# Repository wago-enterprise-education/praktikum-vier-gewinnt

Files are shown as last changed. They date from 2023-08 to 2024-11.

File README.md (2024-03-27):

<meta http-equiv="refresh" content="0; url=https://wago-enterprise-education.github.io/praktikum-vier-gewinnt/docs/index.html">

# Praktikantenprojekt "Vier-Gewinnt"

## Kurzer Überblick

Bei diesem Projekt handelt es sich um ein Projekt für einen Praktikanten welches in der vollständigen Durchführung in etwa 1-3 Tage dauert. Basis des Projekts ist der ESP32. Ziel dabei ist, dass der Praktikant die Grundlagen der Microcontrollerprogrammierung und der Elektronik sowie des Lötens erlernt. Eine kurze Beschreibung des PCBs und der Bedienung kann [hier](docs/Platinenbeschreibung-VierGewinnt.pdf) gefunden werden. Bei Problemen oder Rückfragen kann sich an [uns](#ansprechpartner) gewendet werden.

## Ablauf des Praktikums

### Praktikumsdauer: 1 Tag
1. Vollständiges Löten und Zusammenbauen des Gerätes mithilfe der [Lötanleitung](docs/LoetAnleitung.pdf)
2. Auseinandersetzung mit dem [Aufbau und der Funktionsweise](docs/Platinenbeschreibung-VierGewinnt.pdf) des Spiels

### Praktikumsdauer: 2 - 3 Tage
1. [Aufbau und Programmierung einfacher Schaltungen auf dem Steckbrett](docs/Aufgabenstellung.pdf)
2. Vollständiges Löten und Zusammenbauen des Gerätes mithilfe der [Lötanleitung](docs/LoetAnleitung.pdf)
3. Auseinandersetzung mit dem [Aufbau und der Funktionsweise](docs/Platinenbeschreibung-VierGewinnt.pdf) des Spiels

## Informationen zur Programmierung des Moduls

Zur Programmierung können entweder die "Arduino-IDE" oder "Visual Studio Code" benutzt werden. Programmiert wird auf dem Breakout-Board "DOIT ESP32 DEVKIT V1".

## Hinweise

Während der Bestellung bitte darauf achten, dass bei der Option "Remove Order Number", "Specify a Location" ausgewählt ist.

## Ansprechpartner

<max.steidle@wago.com>

<lucas.krietenstein@wago.com>

<andreas.epp@wago.com>

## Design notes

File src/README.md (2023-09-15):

# Quellcode des Spiels: Vier-Gewinnt
Hier kann der gesamte Quellcode des Spiels gefunden werden. Je nach Ordner, entweder für die Arduino IDE oder für Visual Studio Code.

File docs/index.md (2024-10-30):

---
layout: page
title: 4-Gewinnt
lang: de
lang-ref: index
---

## Kurzer Überblick

Hallo und willkommen bei Ihrem Praktikum bei WAGO. In diesem Modul geht es darum, Vier-Gewinnt aufzubauen, zu löten und gegebenenfalls zu programmieren. Eine kurze Beschreibung des Aufbaus und der Bedienung des Spiels kann [hier](Platinenbeschreibung-VierGewinnt.pdf) gefunden werden. In dem WAGO-Karton den Sie bekommen haben befinden sich alle notwendigen Bauteile, um Vier-Gewinnt aufbauen zu können. Am besten prüfen Sie einmal ob alle Bauteile vorhanden sind. Anhand [dieser Bauteilliste](Bauteilliste.pdf) können Sie sicherstellen, dass der Bausatz vollständig und korrekt ist. Bei Problemen oder Rückfragen können Sie sich gerne an [Herrn Rehburg oder Herr Lauxtermann wenden.](#ansprechpartner)

## Aufbauanleitung

Wenn Sie sichergestellt haben dass der Bauteilsatz vollständig ist, können Sie mit dem Aufbau starten. Um das Spiel aufbauen zu können, werden alle Bauteile in dem WAGO-Karton benötigt. Die Platine dient dabei als Bauteilträger, dort werden also alle Bauteile (Mit Ausnahme des ESP32 und der 9 V Batterie) angelötet. Bevor Sie mit dem Löten anfangen können muss zunächst einmal der Arbeitsplatz eingerichtet werden. Wie er beispielhaft aussehen kann sehen Sie [hier](Arbeitsplatzausstattung.pdf). Wie Sie beim Löten am besten vorgehen wird [hier](LoetAnleitung.pdf) erklärt. Wenn Sie sich an der Anleitung hangeln sollte es beim Aufbau des Spiels keine Probleme geben.

## Informationen zur Programmierung des Moduls

Wenn Sie das Spiel aufgebaut haben können Sie anfangen zu programmieren. Um die Programmierumgebung "Arduino" einmalig einzurichten können Sie sich an [diese Anleitung](Programmierung.pdf) halten. Zur Programmierung können wahlweise entweder die "Arduino-IDE" oder "Visual Studio Code" benutzt werden. Programmiert wird auf dem Breakout-Board "DOIT ESP32 DEVKIT V1". Der fertige Code mit den aktuellen lauffähigen Programmen für Visual Studio Code und Arduino und den Vorlagen der Aufgaben können unter [diesem Link](Bundle.7z) als Zip-Datei heruntergeladen werden. Spielen Sie am am besten das fertige Programm einmal auf den Mikrocontroller um zu prüfen, ob Sie alles richtig verlötet haben. Die Bedienung des Geräts kann [hier](Platinenbeschreibung-VierGewinnt.pdf) nachgelesen werden.

## Aufgaben

Sie haben das Programm auf den ESP32 geladen und alles hat funktioniert? Sehr gut! Dann können Sie mit den nächsten Aufgabenstellungen starten. Im Falle, dass das Spiel noch nicht funktioniert, müssen Sie ihre Platine nochmal überprüfen.

### Aufgabensatz 1

Um das technische Prinzip der LED-Matrix zu verstehen können Sie [diese Aufgaben](Aufgabenstellung.pdf) bearbeiten.

### Aufgabensatz 2

In [diesem Aufgabensatz](ErweiterteAufgaben.pdf) können Sie selbst Hand an den Code legen, sich in den Programmcode hinein arbeiten und einige Zeilen Code eigenständig schreiben. Das dazugehörige Programm ist in vorangegangener Zip-Datei zu finden. Das Programm der Aufgabenstellung muss von Ihnen ergänzt werden.

## Ansprechpartner

<maik.rehburg@wago.com>

<tobias.lauxtermann@wago.com>

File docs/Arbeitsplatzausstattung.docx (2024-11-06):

## Arbeitsplatzausstattung Löten:

Bevor ihr mit der Lötarbeit eures Aufbaus beginnt, solltet ihr den Arbeitsplatz mit den untenstehenden Materialien und Werkzeugen bestücken.

Die Bauteile, Werkzeuge und Materialien solltet ihr in den Blechschränken bzw. Lagertürmen im Elektroniklabor finden, sofern keine anderen Angaben gemacht worden sind. Der fertig bestückte Arbeitsplatz (ohne Materialien) für den Projektaufbau sollte in etwa so aussehen:

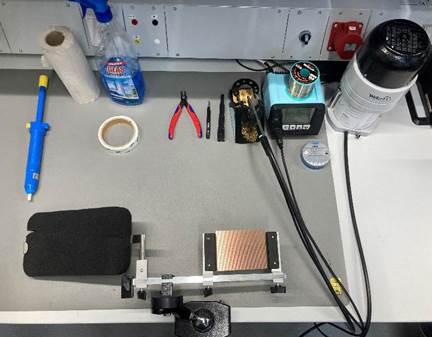
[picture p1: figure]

Lötkolbenset

Absaugung

Lötzinn

Biegelehre

Entlötpumpe

Elektronik-Seitenschneider

Pinzette

Lötfett

Platinenhalterung

Doppelseitiges Klebeband

Glasreiniger

Papier

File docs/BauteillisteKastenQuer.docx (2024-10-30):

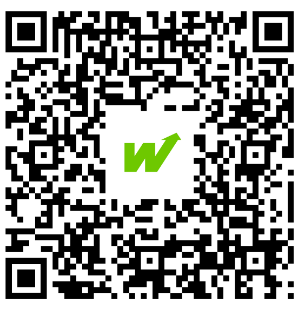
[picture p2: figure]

# Stückliste

Bauteil | Menge | Bauteil | Menge
PCB (Vier-Gewinnt) | 1 | Duo-LED | 30
ESP32 | 1 | Taster | 4
9V Batterie | 1 | Schiebeschalter (angewinkelt) | 1
10 kΩ Widerstände | 4 | Spannungsregler (L7805ACV) | 1
Buchsenleiste (15 Pin) | 2 | Keramikkondensator (330 nF) | 1
Batterieclip | 1 | Keramikkondensator (100 nF) | 1

# Stückliste

Bauteil | Menge | Bauteil | Menge
PCB (Vier-Gewinnt) | 1 | Duo-LED | 30
ESP32 | 1 | Taster | 4
9V Batterie | 1 | Schiebeschalter (angewinkelt) | 1
10 kΩ Widerstände | 4 | Spannungsregler (L7805ACV) | 1
Buchsenleiste (15 Pin) | 2 | Keramikkondensator (330 nF) | 1
Batterieclip | 1 | Keramikkondensator (100 nF) | 1

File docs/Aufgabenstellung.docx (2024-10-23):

# Praktikantenaufgabe “Vier Gewinnt”

# Benötigte Materialien:

- ESP32
- Steckbrett
- Jumperkabel
- 220 Ω Widerstände
- LEDs beliebiger Farbe

# Aufgabenstellung:

Für die kommenden Aufgaben nutzen Sie ein Steckbrett, auf dem Sie verschiedene Schaltungen aufbauen. Auf einem solchen Steckbrett sind die Verbindungspunkte immer entweder in einer Zeile oder Spalte miteinander verbunden, das ist in der folgenden Grafik durch die orangen Linien dargestellt. Stecken Sie den ESP32 wie in der Abbildung dargestellt auf das Steckbrett.

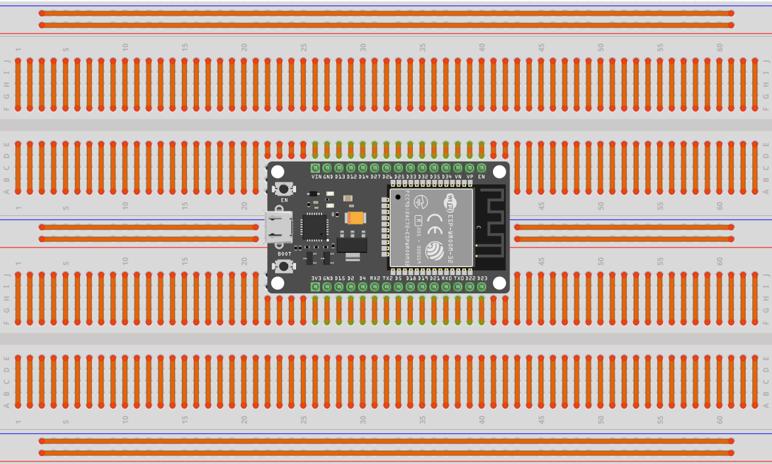
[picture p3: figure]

# Aufgabe 1: Aufbau einer LED

In dieser Aufgabe sollen Sie Leuchtdioden (LEDs) kennenlernen. Wenn durch eine LED-Strom fließt, leuchtet sie. Ist der Strom zu groß, brennt sie durch. Um das zu verhindern, muss immer ein sogenannter Vorwiderstand zwischen der Stromquelle und der LED („vor der LED“) eingebaut werden. Für die folgenden Aufgaben nutzen Sie bitte immer einen 220 Ω Vorwiderstand.

Wenn Sie die LED anschauen, fällt auf, dass sie nicht symmetrisch aufgebaut ist, sondern einer der Anschlussdrähte länger ist. Der lange Anschlussdraht ist der Plus-Pol der LED, der kurze der Minus-Pol (an dieser Seite ist auch das Gehäuse der LED abgeflacht, auch daran können Sie die Seite unterscheiden).

Bauen Sie die Steckbrett-Schaltung der folgenden Abbildung auf. Vom „GND“-Pin des ESP32 gehen Sie mit einer Jumper-Leitung dabei auf die blau markierte Reihe, von dem „3V3“-Pin auf die rot markierte Reihe. Sie können für spätere Schaltungen dann Ground (0V) bzw. 3,3V von diesen Reihen übernehmen.

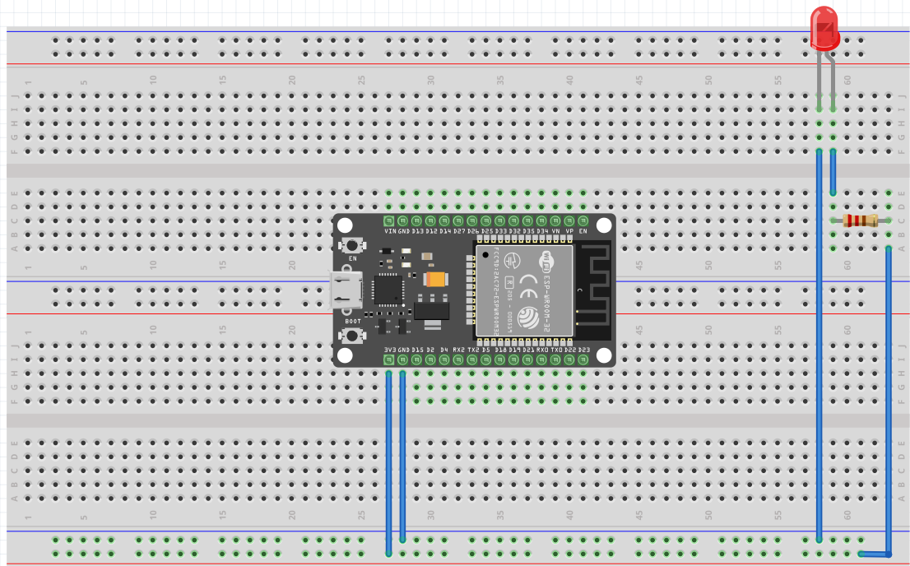
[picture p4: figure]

# Aufgabe 2: LED blinken lassen

Mit dem Aufbau der vorherigen Aufgabe liegt immer Spannung an der LED an und sie leuchtet immer. Wir wollen sie aber selbst ein- und ausschalten können. Dafür nutzen wir einen Ausgangspin der ESP32, den wir programmieren können. Bauen Sie als erstes diese Schaltung auf und öffnen Sie ein neues Projekt in der Arduino IDE:

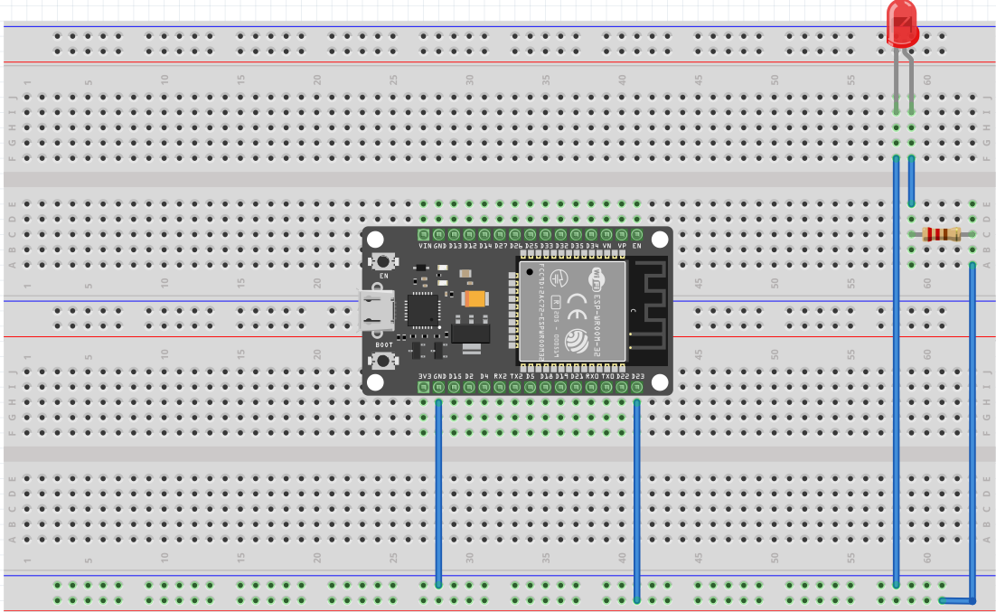
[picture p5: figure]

Der Ausgang, an dem der Widerstand angeschlossen ist, ist mit „D23“ bezeichnet. Das ist der Pin mit der Nummer 23. Damit wir nicht im Programm die Nummer verwenden müssen, um die LED ansteuern zu können, „merken“ wir uns den Pin und definieren dafür eine eigne Bezeichnung. Das macht man durch #define<Platzhalter> <Wert>, dass man über die loop()- und setup()-Funktion schreiben. In diesem Fall also: #define LED 23

Jetzt müssen wir noch konfigurieren, dass dieser Pin als Ausgang genutzt werden soll. Das muss nur einmal beim Starten des ESP32 ausgeführt werden und wird daher in der setup()-Funktion geschrieben. Die Funktion, um einen digitalen Ein- oder Ausgang zu konfigurieren ist pinMode(<Pin>, <INPUT/OUTPUT>). Für alle Stellen im Programm, in denen die Pin-Nummer benötigt wird, können wir jetzt den Platzhalter eintragen, also:

pinMode(LED, OUTPUT);

Damit „weiß“ das Programm, dass dieser Pin, an den die LED über den Vorwiederstand angeschlossen ist, einen Wert High/Low ausgeben soll. Das müssen wir im nächsten Schritt auf diesen Pin schreiben. Das soll immer wieder passieren, muss also in die loop()-Funktion geschrieben werden. Wir wollen einen digitalen Wert schreiben auf den Ausgang, genauso heißt auch die Funktion

digitalWrite(LED, HIGH);

Damit wird die LED eingeschaltet. Um sie wieder auszuschalten, schreibt man LOW statt HIGH. Eine blinkende LED schaltet immer zwischen an und aus – mit einem zeitlichen Versatz dazwischen. Um eine gewisse Zeit zu warten nutz man

delay(<Zeit in Millisekunden>);

Nutzen Sie die Funktionen, die Sie kennengelernt haben und lassen Sie die LED in regelmäßigen Zeitabständen (z.B. 2 Sekunden) blinken

# Aufgabe 3: Masse schalten

So wie man einen Pin des ESP32 als digitalen Ausgang nutzen und programmieren kann, um eine Spannung auszugeben, kann man auch einen Pin dafür verwenden, um Masse zu schalten (also 0V ausgeben). Bauen Sie zuerst die folgende Schaltung auf dem Steckbrett nach:

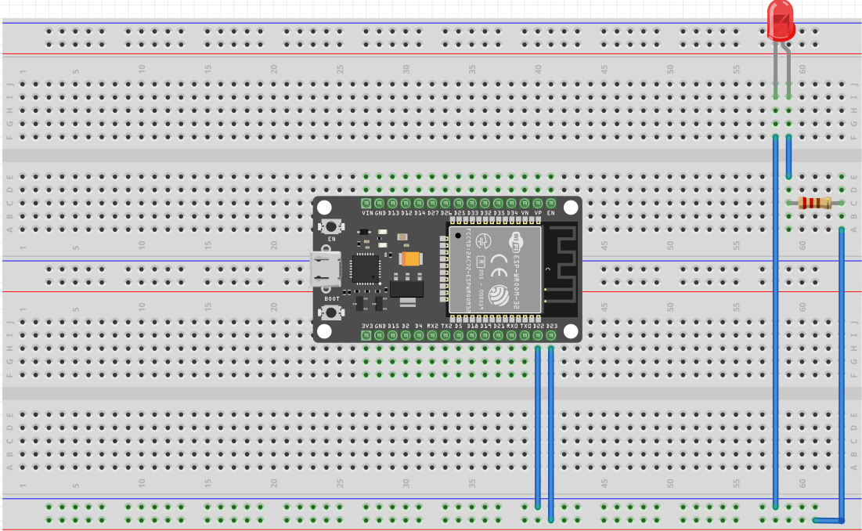
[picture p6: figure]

Die Masse liegt nun auf dem Pin „D22“ diesen können Sie sich wieder in einem Platzhalter abspeichern, um diesen im restlichen Programm zu verwenden. Außerdem muss dieser Pin ebenfalls in der setup()-Funktion als Ausgang konfiguriert werden. Im Anschluss können Sie diesen Pin wieder in der loop()-Funktion programmieren. Um Masse zu schalten, wird dieselbe Funktion, wie zum Ein- und Ausschalten der LED verwendet, da es nichts anderes ist, als eine Spannung von 0V (also LED ausschalten) abzugeben. Versuchen Sie die LED wieder zum Blinken zu bekommen, indem Sie über den Pin 23 konstant eine Spannung von 3,3V anlegen und nur über den Masse-Pin 22 die LED steuern.

# Aufgabe 4: Eigene LED-Matrix

Da unser 4-Gewinnt Spielfeld aus 6 Spalten und 5 Reihen besteht, benötigen Sie 30 LEDs. So viele programmierbare Ausgänge besitz der ESP32 allerdings nicht. Aus diesem Grund müssen Sie sich mit einem „Trick“ behelfen. Jede LED einer Zeile Ihrer eigenen LED-Matrix wird mit demselben Pin verbunden, der eine Spannung von 3,3V abgibt, und jede LED einer Spalte wird mit demselben Pin verbunden, über den Sie dann für die Spalte Masse schalten können. Somit brauchen wir nur 11 Pins (6 Spalten + 5 Zeilen) anstelle von 30. Wie steuert man nun einzelne LEDs auf der Matrix an?

Das System funktioniert wie ein Graph mit einer x- und einer y-Achse. Möchte man eine bestimmte LED ansteuern schaltet man Masse auf der passenden Spalte (die x Koordinate) und die Spannung auf der Passenden Zeile (die y Koordinate). Alle anderen Spalten und Zeilen werden nicht angesteuert und aus diesem Grund leuchtet nur die gewünschte LED.

Bauen Sie den folgenden Schaltplan auf dem Steckbrett nach. Dieser Aufbau demonstriert das Prinzip auf einer kleinen 2x2 Matrix. Dabei ist die Zeile 1 (das linke LED-Paar) mit dem Pin „D13“ verbunden und die Zeile 2 mit dem Pin „D22“. Außerdem ist die erste Spalte (die beiden linken LEDs der LED-Paare) mit dem gemeinsamen Pin „D12“ und die zweite Spalte mit dem Pin „D23“ verbunden.

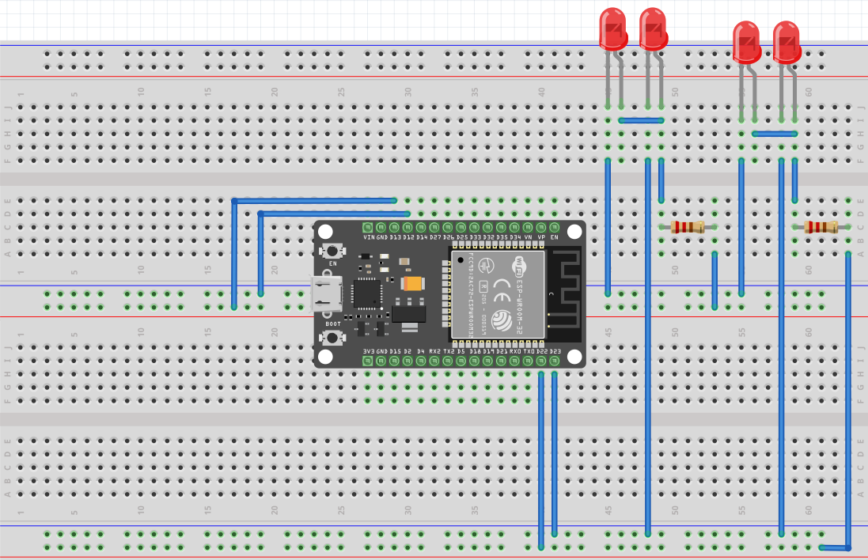
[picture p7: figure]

Versuchen Sie die LED, die in der ersten Spalte und in der ersten Zeile liegt, einzuschalten, ohne das eine andere LED leuchtet.

Beim 4-Gewinnt Spiel leuchtet allerdings nicht immer nur eine LED, sondern viele LEDs gleichzeitig. Was Passiert, wenn Sie versuchen, zwei diagonale LEDs anzusteuern (z.B. Zeile 1, Spalte 1 und Zeile 2, Spalte 2)?

Wie Sie gemerkt haben, leuchten alle 4 LEDs auf, was auch logisch ist, wenn man näher darüber nachdenkt. Aus diesem Grund benötigen Sie einen zweiten „Trick“. Steuern Sie nun die LEDs spaltenweise und zeitversetzt an. Dadurch verhindern wir das LEDs zeitgleich leuchten, die nicht zusammen leuchten sollten. Diesen Vorgang wiederholen wir in einer so hohen Frequenz, dass unser Auge nicht wahrnimmt, dass die LEDs ständig ein- und ausgeschaltet werden. Schreiben Sie ein Programm, dass die eine LED einschaltet und für einen kurzen Moment (z.B. 1 Millisekunde) leuchten lässt. Im Anschluss soll diese LED wieder ausgeschaltet werden und die diagonal gegenüberliegende LED soll für einen kurzen Moment leuchten. Durch die Arbeitsweise der loop()-Funktion wird dieser Vorgang kontinuierlich wiederholt (Tipp: um das Programm zu Pausieren können Sie wieder die Funktion delay() verwenden).

Wenn Sie das Programm richtig geschrieben haben, sollten nun nur die beiden LEDs auf einer Diagonalen zeitgleich leuchten. Dies ist aber, wie Sie nun wissen, nur die halbe Wahrheit. Sie können mit der Verzögerung rumexperimentieren und testen mit welcher Frequenz unser Auge die Täuschung bemerkt.

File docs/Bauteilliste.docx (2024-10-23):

# Bauteilliste

Bauteil | Anzahl | Beschreibung
Platine | 1 | Der Bauteilträger auf der die Bauteile aufgelötet werden. Er hat die Bezeichnung „Vier_Gewinnt V2.1“

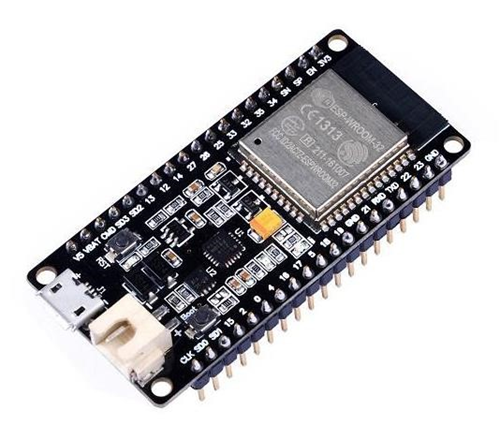
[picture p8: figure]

ESP32 | 1 | Der Mikrocontroller auf dem das Programm laufen wird. Er sollte ungefähr so aussehen:
9 V Batterie | 1 | Die Spannungsversorgung für die Platine.
10 kΩ Widerstände | 4 | Die Farbringe auf dem Widerstand sind in folgender Reihenfolge angeordnet: Braun-Schwarz-Schwarz-Rot-Braun
Buchsenleiste | 2 | Buchsenleiste mit 15-Pins. Dort wird der ESP32 später eingesetzt.

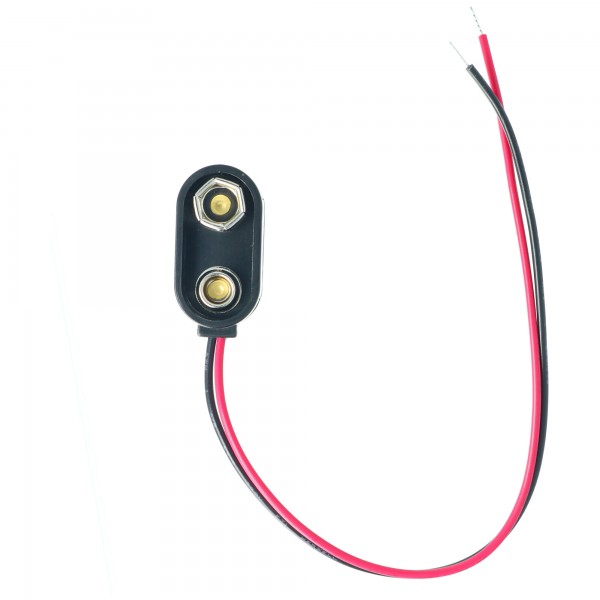
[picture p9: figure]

Batterieclip | 1 | Beispielsweise:
Duo-LED | 30 | LEDs mit 3 Beinchen.
Taster | 4 | Kleine Taster mit 4 Beinchen.
Schiebeschalter | 1 | Einen angewinkelten Schiebeschalter.
Spannungsregler | 1 | Einen Spannungsregler mit der Bezeichnung L7805.
Keramikkondensator | 1 | Ein Kondensator mit gleich langen Beinchen und der Bezeichnung 334.
Keramikkondensator | 1 | Ein Kondensator mit gleich langen Beinchen und der Bezeichnung 104.

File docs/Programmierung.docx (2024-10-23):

# Programmierung des ESP32

Um den ESP32 programmieren zu können muss sich zuerst mit dem Gerät verbunden werden. Dafür steckt man ein USB-Kabel jeweils in den ESP32 und in einen Computer, mit dem Sie gerne programmieren möchten. Um nun festzustellen an welchen Port der ESP32 angeschlossen ist, muss der Gerätemanager geöffnet werden. Diesen finden Sie über die Windows-Suchleiste. Nachdem Sie das Programm geöffnet haben öffnen Sie den Reiter „Anschlüsse (COM & LPT). Sie finden den passenden Port unter dem Namen „Silicon Labs“. In vorangehendem Beispiel ist es der COM4-Anschluss.

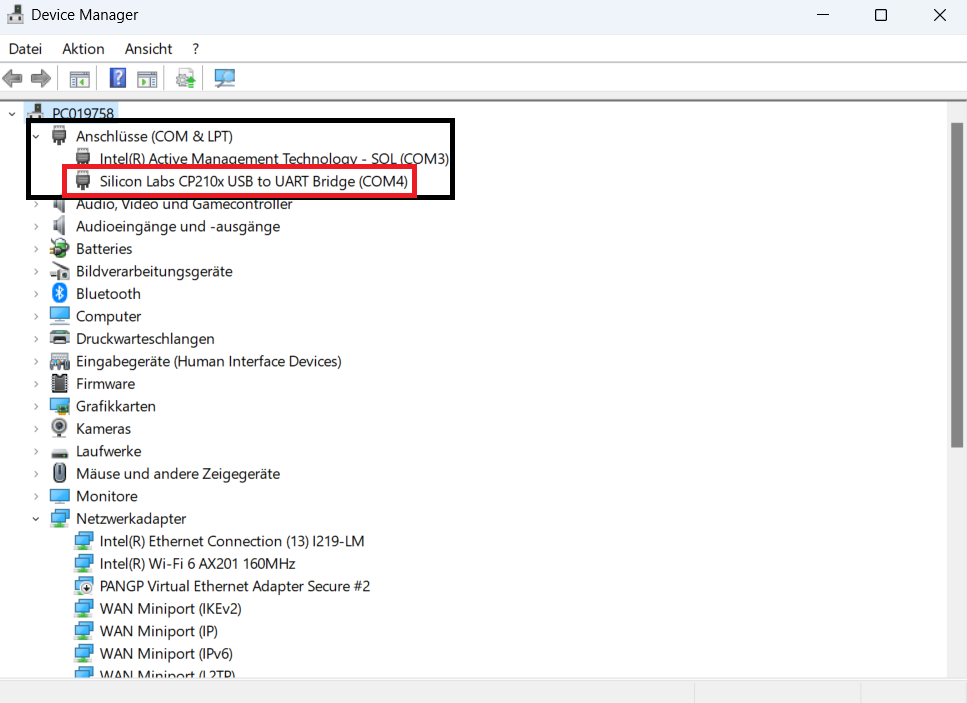
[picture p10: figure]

Wenn dies soweit funktioniert hat kann wahlweise die Arduino-IDE oder Visual Studio Code geöffnet werden. Im Folgenden wird das Programmieren in der Arduino-IDE beschrieben. Dafür muss zunächst die Arduino-IDE geöffnet werden. Nach einer kurzen Ladezeit sollte die Programmierumgebung öffnen. Dort klicken Sie auf „Board wählen“ und den Port, der bei Ihnen im Gerätemanager angezeigt wurde:

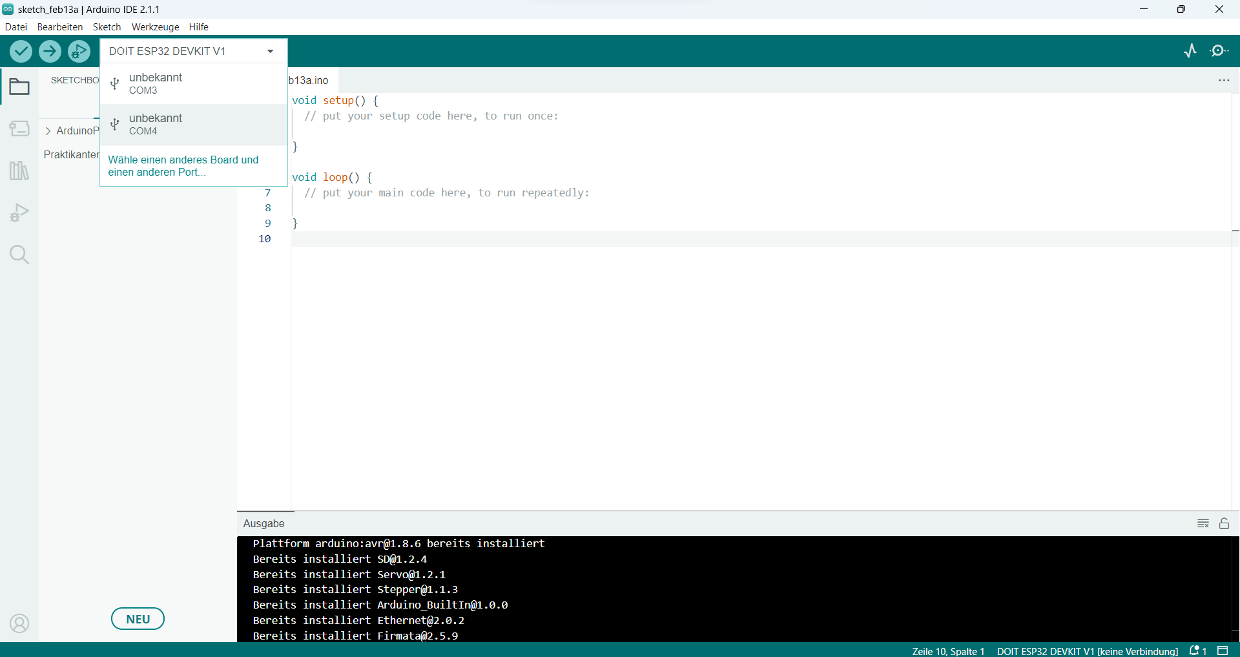
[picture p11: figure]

Nachdem Sie den passenden Port angeklickt haben öffnet sich ein weiters Fenster:

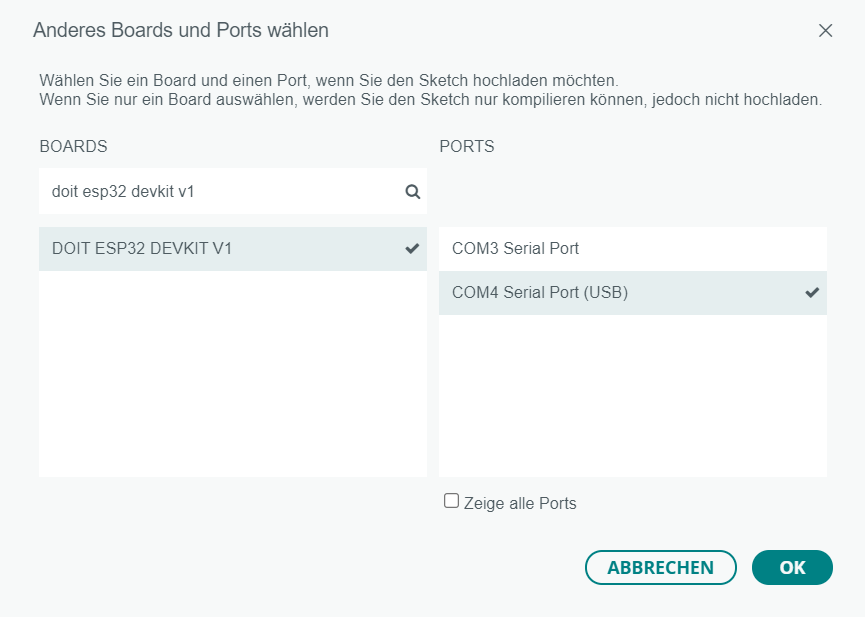
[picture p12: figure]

Dort geben sie in die Suche folgenden Begriff ein: „doit esp32 devkit v1“. Dann müssen Sie das Board auswählen (der Haken bestätigt die Auswahl) und mit „OK“ bestätigen. Nun kann ein Programm geschrieben werden.

Diese Navigationsleiste ist oben links zu finden. Mithilfe des linken Button kann der Code auf Fehler überprüft werden. Mit dem rechten Button kann das Programm auf den ESP32 hochgeladen werden.

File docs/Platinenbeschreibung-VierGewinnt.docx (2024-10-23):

# Platinenbeschreibung

Diese Anleitung beschreibt den Aufbau und die Funktion des Spiels: „Vier Gewinnt“.

## Beschreibung des Schaltplans

Die Energieversorgung für das Spiel ist folgendermaßen aufgebaut:

Eine 9V Batterie liefert die notwendige Spannung für den kleinen Computer. Allerdings braucht dieser nur 5V. Um die Spannung auf das erforderliche Niveau herunterzuregeln wird ein Spannungsregler verbaut. Die zusätzlichen Bauteile um den Spannungsregler herum (Diode, Kondensator) sorgen nur dafür, dass ein normaler Betrieb möglich ist.

Der ESP32 wurde wie folgt angeschlossen:

Die Taster wurden an den Eingängen des ESP32 angeschlossen. Dort sind auch sogenannte Pull-Down-Widerstände parallelgeschaltet, deren Aufgabe es ist, den Eingängen einen festen Zustand zuzuordnen, wenn der Taster nicht betätigt ist. Die LEDs sind an dem ESP32 spaltenweise mit Ihrem „Masse-Pin“ und zeilenweise mit Ihrem „+-Pin“ an den digitalen Ausgängen des Microcontrollers angeschlossen.

## Beschreibung des Spielablaufs

Startet man das Spiel über den Schiebeschalter, gelangt man zuerst in ein Menü, in welchem man den Spielmodus auswählen kann. Die angezeigte Nummer kennzeichnet, ob es sich um Einzelspieler (Nummer 1) oder Mehrspieler (Nummer 2) handelt. Anzuwählen ist jeweils über die Taster mit „Pfeiltaste rechts“ und „Pfeiltaste links“. Die Auswahl bestätigt man mit „Pfeiltaste runter“. Der Einzelspielermodus ermöglicht ein Spiel gegen den Computer. Der Mehrspielermodus ist dazu geeignet, um gegen einen anderen Spieler im Hot-Seat-Modus zu spielen (Mit einem Gegenspieler an einem Gerät). Die Spielregeln entsprechen dabei den exakten Spielregeln eines Vier-Gewinnt-Spiels, wobei dieses Board nur eine Spielfeldgröße von 6x5 hat (Im Original sind es 7x6). Gewonnen hat dabei immer der Spieler, der eine Viererreihe (entweder senkrecht, waagerecht oder diagonal) gebildet hat. Mit den Pfeiltasten „Links“ und „Rechts“ kann eine Spalte angewählt werden. Platziert wird er mit der Pfeiltaste „runter“. Über den „Reset-Knopf“ kann das Spiel jederzeit, durch halten des Knopfes abgebrochen werden. Dieser muss auch bei Spielende betätigt und gehalten werden! Dann erscheint erneut das Auswahlmenü.

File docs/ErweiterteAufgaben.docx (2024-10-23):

# Erweiterte Aufgaben

# Einführung

Sie haben sich nun intensiv mit dem Projekt Vier-Gewinnt auseinandergesetzt. Dabei lag der Fokus zum größten Teil auf der Hardware (dem technischen Teil). Mit den folgenden Aufgaben sollen sie sich näher mit dem Programm und der Spiellogik vertraut machen. Dafür haben wir Ihnen ein Grundgerüst zur Verfügung gestellt mit dem Sie arbeiten können. Damit sie sich in dem gegebenen Code zurechtfinden und diesen erweitern können folgen einige Erläuterungen. Außerdem existiert eine „Musterlösung“, welche Sie gerne zur Hilfestellung verwenden können. Seien Sie allerdings ehrgeizig und geben Sie nicht zu früh auf, durch eigenes Denken lernen Sie mehr als durch Abschreiben 😉.

# Begriffserklärung

In den folgenden Aufgaben werden einige Fachbegriffe verwendet. Die häufigsten werden im Folgenden einmalig erklärt und dann im weiteren Verlauf als gegeben vorausgesetzt. Falls die Erklärungen nicht beim Verständnis weiterhelfen, lohnt es sich auch die Begriffe im Internet nachzuschlagen. Des Weiteren wird in diesem Dokument zur Beschreibung der Syntax ein Format verwendet, bei dem Spitzklammern (<>) wie Platzhalter behandelt werden. Diese sollen nicht im Code übernommen werden, sondern müssen durch passende Namen oder ähnliches ersetzt werden.

Beispiel:

lm.<Methodenname>(<Parameterliste>)

kann durch

lm.placeStone(2, Color::GREEN);

ersetzt werden.

Variable: Eine Variable ist eine Art Platzhalter für einen Wert. So kann man Werte speichern und anpassen. Der Zugriff auf diese Werte erfolgt durch den Namen der Variable. In einer Variable können nur Werte des gleichen Typs gespeichert werden. Für eine Liste der verschiedenen Typen können Sie die Arduino Reference verwenden, denn dort befindet sich ein Unterpunkt namens „Variables“: https://docs.arduino.cc/language-reference/de/

Methode: Um ein Programm strukturierter zu gestalten verwendet man sogenannte Methoden (oder auch Funktionen). In sie kann man verschiedene Befehle reinschreiben, die häufiger verwendet werden. Sie besitzen ebenfalls einen Namen und können durch diesen aufgerufen werden. Außerdem kann man einer Methode Parameter übergeben. Diese funktionieren wie Variablen, können allerdings nur in der Methode verwendet werden.

Array: Ein Array ist eine Variable in der mehr als nur ein Wert gespeichert werden kann. Die Werte haben eine Reihenfolge/ Ordnung, durch diese kann man steuern auf welchen Wert man zugreifen kann. Ein Array kann mehrere Dimensionen besitzen. Für unseren Fall sind es Arrays mit zwei Dimensionen. Diese können Sie sich vorstellen, wie eine Art Koordinatensystem, wo man durch zwei Koordinaten einen genauen Punkt/ Wert identifizieren kann. Dieses Prinzip kennen Sie eventuell auch durch das Spiel „Schiffe versenken“.

# Main

Die Main-Datei hat zwei Aufgaben: Zum einen wird hier die Pinbelegung festgelegt und im Setup richtig konfiguriert und zum anderen wird hier die Spiellogik implementiert und geregelt. Für Sie relevant sind dabei nur die Methoden loop() und readButtons(), da der Rest bereits so vorbereitet wurde, dass es mit der von Ihnen fertiggestellten Platine kompatibel ist. Neben den beiden Methoden werden Sie für die Erweiterungen auch einige der Variablen brauchen, die oben initialisiert wurden. Dazu werden Sie allerdings passende Hinweise bei den Aufgabenbeschreibungen finden.

# LEDMatrix und Color

Die Datei mit dem Namen LEDMatrix.cpp ist dafür da, dass man das sichtbare Spielfeld (also die LEDs) ansteuern und verändern kann. Auch hier wurden Ihnen bereits einige Methoden zur Unterstützung bereitgestellt. Hier sind nur die Methoden setLightValue(), placeStone() und printNumber() für Sie interessant.
Die Datei mit dem Namen Color.h ist ein sogenannter Enum, welcher unsere Farblogik regelt. Enums werden dafür verwendet, um feste Zustände abzubilden, so wie bei uns die Farben einer LED. Dabei unterscheiden wir zwischen den Zuständen OFF, RED, GREEN, FLASH_RED und FLASH_GREEN. Auf diese Zustände kann man zugreifen, indem man folgende Syntax verwendet: Color::<Zustand>

# Aufgabe 1 – Nummern anzeigen

Wie Sie bereits gesehen haben, hat das Vier-Gewinnt Spiel ein Menü, in dem ein Spielmodus ausgewählt werden kann. Die Spielmodi bilden wir durch Nummern ab (eine Eins für den Einspieler und eine Zwei für den Zweispieler Modus). Die Methode, welche die Nummern auf der LED-Matrix anzeigt haben wir Ihnen breitgestellt (printNumber()). Damit Sie besser verstehen, wie der Zustand der LEDs im Programm geändert werden kann, sollen Sie sich die Methode genauer anschauen und erweitern. Die Erweiterung soll dafür sorgen, dass nicht nur die Nummern 1 und 2 angezeigt werden können, sondern alle Nummern von 0-4. Außerdem soll die loop()-Methode in der Main-Datei ebenfalls so angepasst werden, dass die Nummern in einem Zyklus auf den LEDs abgebildet wird. Achten Sie darauf, dass Sie Delays mit einbauen, damit die Nummern lange genug angezeigt werden. Dabei kann die Variable currentColumn angepasst und als Parameter an die printNumber()-Methode übergeben werden.

## Hinweise

Um einen Zyklus zu realisieren, genügt es nicht den Wert immer wieder zu erhöhen. Es muss einen Kipppunkt geben, an dem der Wert wieder zurückgesetzt wird. Dies lässt sich leicht mit dem sogenannten Modulo-Operator lösen. Dieser gibt den Restbetrag einer ganzzahligen Division zurück. Ein Beispiel: 15 ÷6=2 Rest 3 . Also würde der Modulo-Operator den Wert 3 berechnen. So haben Sie wahrscheinlich auch die Division in der Grundschule kennengelernt, bevor sie mit Dezimalzahlen gerechnet haben. Im Programm schreiben Sie für den Modulo-Operator ein Prozentzeichen (%), also 15 % 6. Mit der Rechnung:

currentColumn = (currentColumn + 1) % 5;

kriegen Sie den gewünschten Zyklus von 0 bis 4. Überprüfen Sie die Rechnung gerne mit einigen Werten, um diese nachzuvollziehen.

In der Methode printNumber() wird ein Switch-Case verwenden. Dies ist eine abgewandelte Form einer If-Abfrage, welche in bestimmten Fällen besser zu lesen ist. Damit Sie diese verstehen und anpassen können finden Sie hier einen Link zur Dokumentation von Switch-Cases: https://docs.arduino.cc/language-reference/de/struktur/control-structure/switchCase/

# Aufgabe 2 – Auswahlleiste

Vor jedem Spielzug befindet sich der Spieler bei unseren Vier-Gewinnt in einer Art Auswahlleiste (In der man die Spalte anwählen kann, wo der Stein platziert werden soll). In dieser kann man sich mit den Tastern bewegen, ohne das Spiel zu beeinflussen. Erst wenn der Taster nach unten betätigt wird, wird der Stein auch wirklich platziert. Diese Auswahlleiste sollen Sie nun Implementieren. Um dies zu realisieren müssen Sie die Method readButtons() in der Main-Datei und die Methode setLightValues() in der LEDMatrix.cpp anpassen.

Beginnen Sie mit der Methode setLightValues(). Diese erhält drei Parameter: die aktuelle Spalte, die eingeschaltet wird, die vorherige Spalte und die Farbe, die die LED in der Auswahlleiste annehmen soll. Damit die Änderungen auf dem Spielfeld angezeigt werden muss der Zweidimensionale Array LEDValues angepasst werden, wie Sie es bereits in der printNumbe() Methode getan haben. Allerdings gibt es einen leichteren Weg, um einzelne Werte zu verändern. Mit folgender Syntax greifen Sie auf einzelne Werte des Arrays zu:

LEDValues[<x-Koordinate>] [<y-Koordinate>];

Dabei ist die LED oben links die LED mit den Koordinaten (0;0). Die Werte, die also möglich sind, liegen für die x-Koordinate zwischen 0 und Anzahl Spalten – 1 und für die y-Koordinaten zwischen 0 und Anzahl Reihen – 1.

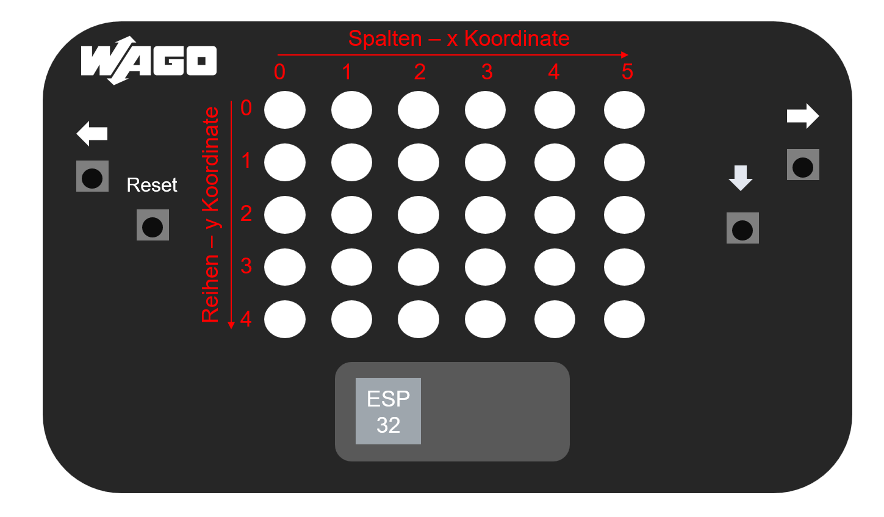
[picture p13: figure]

Der Befehl LEDValues[3] [1] greift also auf folgende LED zu:

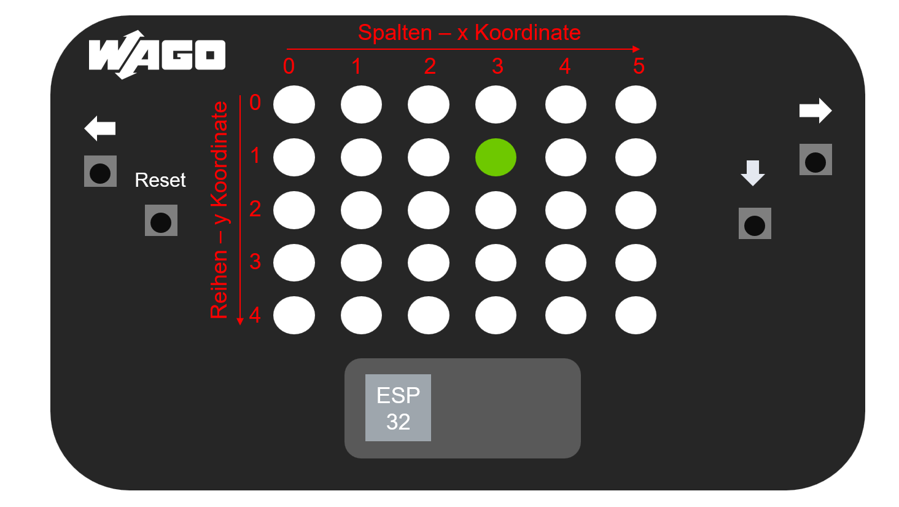
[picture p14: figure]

Da wir uns in der obersten Reihe befinden bleibt die y-Koordinate für die auswahlleiste immer 0. Wenn Sie sich vorstellen, dass Sie den Stein (LED) mit den Tastern in dieser Auswahlleiste navigieren wollen, müssen Sie dafür die LED, die vorher geleuchtet hat ausschalten und die neue LED muss in der übergebenen Farbe aufleuchten. Die Farbe, die übergeben werden muss, ist:

Color::FLASH_GREEN,

damit die LED am Ende auch blinkt, wie im richtigen Spiel. Versuchen Sie dies im Programmcode umzusetzen

Nun bearbeiten wir die Methode readButtons(). Hier werden die Taster eingelesen und auf das gegebene Eingabe Signal reagiert. Um die Taster einzulesen kann die Methode digitalRead() verwendet werden. Diese erhält als Parameter den Pin, welcher gelesen werden soll und gibt einen digitalen Wert (also 0/LOW oder 1/HIGH) zurück. Mit der Abfrage

if ( digitalRead(buttonL) )

wird abgefragt, ob der Taster links gedrückt wurde. Dies können Sie für den rechten Taster identisch machen. Da keine zwei Taster gleichzeitig gedrückt werden sollen, kann man hier if…else if verwende und keine zwei einzelnen If-Anweisungen. Wenn der linke Taster gedrückt wurde, muss die aktuelle Spalte um ein reduziert werden und für den rechten Taster um eins erhöht. Allerdings muss hier berücksichtigt werden, dass das Spielfeld links und rechts einen Rand hat. Hier können Sie wieder die Formel für den Zyklus verwenden. Also:

currentColumn = (currentColumn + 1) % nColumns

für den rechten Taster und

currentColumn = (currentColumn – 1 + nColumns) % nColumns

für den linken. Das zusätzliche Aufaddieren bei der Formel für den Linken Taster ist dafür da, um negative Werte zu vermeiden. Bevor Sie die aktuelle Spalte anpassen müssen Sie sich den aktuellen Wert in einer Hilfs-Variable abspeichern, da Sie diesen Wert als Parameter an die Methode setLightValue() übergeben müssen. Nun haben Sie alle Berechnungen durchgeführt und können Ihre Werte an die Methode übergeben, dabei würde ich Ihnen empfehlen den Methodenaufruf am Ende außerhalb der If-Anweisungen durchzuführen. Da die Methode in einer anderen Datei implementiert ist, müssen Sie die Methode mit

lm.<Methodenname>(<Parameterliste>)

aufrufen. Testen Sie Ihr Programm.

Wie Ihnen beim Testen mit Sicherheit aufgefallen ist, führt das einmalige Betätigen des Tasters zu mehreren Verschiebungen in der Auswahlleiste. Dies liegt daran, dass die readButtons()-Methode sehr häufig und schnell hintereinander in der loop()-Methode aufgerufen wird. Deshalb kann man nicht so schnell drücken, wie die Methode aufgerufen wird. Aus diesem Grund kann man die Hilfsvariable lastButton nutzen. Diese Speichert den Pin des letzten Tasters. Wir nun ein Taster gedrückt, dann passt man diese Variable auf den aktuellen Taster an, zum Beispiel:

lastButton = buttonL.

Nun kann man die If-Anweisung erweitern und sagen, dass die aktuelle Spalte nicht nur angepasst werden soll, wenn ein Taster gedrückt wird, sondern auch wenn dieser vorher nicht gedrückt wurde. Des Weiteren muss ein else-Zweig hinzugefügt werden, der die lastButton Variable wieder zurücksetzt, wenn kein Taster mehr gedrückt wird. Nun sollte Ihre Auswahlleiste richtig funktionieren.

# Aufgabe 3 – Steinplatzieren

Zum Schluss wollen wir uns nicht nur in der Auswahlleiste bewegen, sondern auch wirklich Steine platzieren. Dafür müssen zwei Änderungen vorgenommen werden: Die readButtons() Methode muss erweitert werden, so dass auch der Taster nach unten erkannt wird und es muss die Methode placeStone() in LEDMatrix.cpp implementiert werden.

placeStone() erhält als Parameter die Spalte, in der der Stein platziert werden soll und die Farbe. Um nach der richtigen Stelle in der angegebenen Spalte zu Suchen empfiehlt sich eine For-Schleife zu verwenden. Eine Beschreibung dieser Schleife finden Sie hier: https://docs.arduino.cc/language-reference/de/struktur/control-structure/for/. Eine For-Schleife ist eine Zählerschleife. Mit dieser können Sie die Zeilen in der übergebenen Spalte nacheinander überprüfen. Dabei sollten Sie unten beginnen, da der Stein bei einem echten Vier-Gewinnt Spiel durch die Gravitation nach unten fallen würde. Sobald Sie eine LED finden, die ausgeschaltete ist können Sie den Stein dort Platzieren, indem Sie die LED auf den übergebenen Wert setzten. Danach können Sie die Methode mit dem Schlüsselwort return beenden.

Für den Taster nach unten können Sie so vorgehen wie für die anderen Taster. Allerdings wird hier die Methode placeStone() aufgerufen und nach dem Aufruf wird die aktuelle Spalte auf 0 gesetzt.

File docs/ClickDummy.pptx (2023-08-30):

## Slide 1

ESP32

←

←

Reset

↑

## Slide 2

ESP32

←

←

Reset

↑

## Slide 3

ESP32

←

←

Reset

↑

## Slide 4

ESP32

←

←

Reset

↑

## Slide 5

ESP32

←

←

Reset

↑

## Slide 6

ESP32

←

←

Reset

↑

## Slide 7

ESP32

←

←

Reset

↑

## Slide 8

ESP32

←

←

Reset

↑

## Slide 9

ESP32

←

←

Reset

↑

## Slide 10

ESP32

←

←

Reset

↑

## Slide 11

ESP32

←

←

Reset

↑

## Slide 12

ESP32

←

←

Reset

↑

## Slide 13

ESP32

←

←

Reset

↑

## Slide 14

ESP32

←

←

Reset

↑

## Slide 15

ESP32

←

←

Reset

↑

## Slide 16

ESP32

←

←

Reset

↑

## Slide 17

ESP32

←

←

Reset

↑

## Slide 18

ESP32

←

←

Reset

↑

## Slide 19

ESP32

←

←

Reset

↑

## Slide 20

ESP32

←

←

Reset

↑

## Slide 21

ESP32

←

←

Reset

↑

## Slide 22

ESP32

←

←

Reset

↑

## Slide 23

ESP32

←

←

Reset

↑

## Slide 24

ESP32

←

←

Reset

↑

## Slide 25

ESP32

←

←

Reset

↑

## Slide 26

ESP32

←

←

Reset

↑

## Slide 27

ESP32

←

←

Reset

↑

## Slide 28

ESP32

←

←

Reset

↑

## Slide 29

ESP32

←

←

Reset

↑

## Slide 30

ESP32

←

←

Reset

↑

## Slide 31

ESP32

←

←

Reset

↑

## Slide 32

ESP32

←

←

Reset

↑

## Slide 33

ESP32

←

←

Reset

↑

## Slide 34

ESP32

←

←

Reset

↑

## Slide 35

ESP32

←

←

Reset

↑

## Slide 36

ESP32

←

←

Reset

↑

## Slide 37

ESP32

←

←

Reset

↑

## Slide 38

ESP32

←

←

Reset

↑

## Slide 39

ESP32

←

←

Reset

↑

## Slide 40

ESP32

←

←

Reset

↑

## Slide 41

ESP32

←

←

Reset

↑

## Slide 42

ESP32

←

←

Reset

↑

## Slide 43

ESP32

←

←

Reset

↑

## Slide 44

ESP32

←

←

Reset

↑

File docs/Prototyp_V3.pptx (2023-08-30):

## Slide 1

ESP32

←

←

Reset

↑

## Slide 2

ESP32

←

←

Reset

↑

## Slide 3

ESP32

←

←

Reset

↑

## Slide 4

ESP32

←

←

Reset

↑

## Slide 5

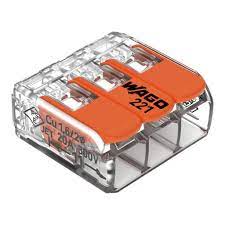
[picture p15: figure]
WAGO | Verbindungsklemme 221-413 ab 50 Stück günstig vom Hersteller kaufen
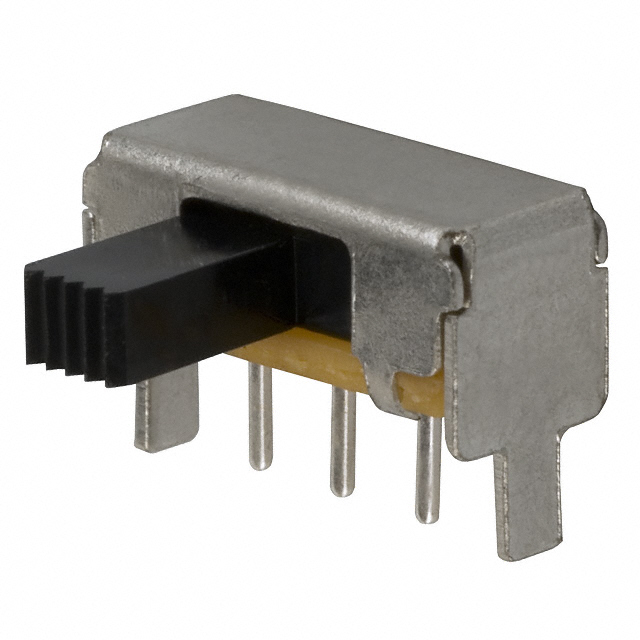
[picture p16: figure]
EG1206A
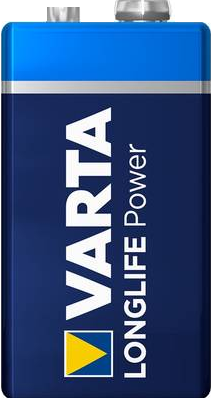
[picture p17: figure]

ESP32

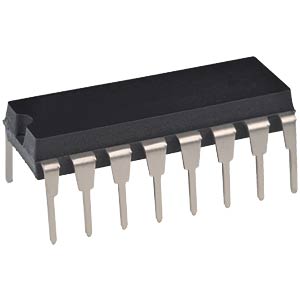
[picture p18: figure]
Multiplexer, 2-CH, 2 ... 6 V, DIL-16 NXP 74HC158

6 x 5 LED-Matrix

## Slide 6

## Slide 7

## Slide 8

WAGO 221

WAGO 221

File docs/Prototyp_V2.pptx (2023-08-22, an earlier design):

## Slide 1

Neues Spiel

ESP32

Spiel starten

On/Off

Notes: Entwurf 1

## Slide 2

ESP32

On/Off

Neues Spiel

↓

←

→

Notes: Entwurf 2

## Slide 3

ESP32

On/Off

Neues Spiel

↓

←

→

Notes: Entwurf 2

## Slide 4

ESP32

On/Off

Neues Spiel

↓

←

→

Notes: Entwurf 2

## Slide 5

ESP32

On/Off

Neues Spiel

↓

←

→

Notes: Entwurf 2

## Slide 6

ESP32

On/Off

Neues Spiel

↓

←

→

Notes: Entwurf 2

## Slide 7

ESP32

On/Off

Neues Spiel

↓

←

→

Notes: Entwurf 2

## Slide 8

ESP32

On/Off

Neues Spiel

↓

←

→

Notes: Entwurf 2

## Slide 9

ESP32

On/Off

Neues Spiel

↓

←

→

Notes: Entwurf 2

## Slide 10

9V

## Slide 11

ESP32

←

←

Reset

↑

ON

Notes: Entwurf 2

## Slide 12

ESP32

←

←

Reset

↑

ON

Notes: Entwurf 2

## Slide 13

ESP32

←

←

Reset

↑

ON

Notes: Entwurf 2

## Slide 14

ESP32

ON/OFF

Reset

↑

←

↑

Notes: Entwurf 2

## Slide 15

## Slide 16

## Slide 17

WAGO 221

WAGO 221

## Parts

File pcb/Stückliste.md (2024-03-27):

# Stückliste

- gedruckte PCB (Vier-Gewinnt V2.1)
- ESP32 (DOIT DEVKIT V1)
- 9V Batterie
- 4x 10 kΩ Widerstände
- 2x Buchsenleisten (jeweils 15 Pin)
- [Batterieclip 0,25€/Stk.](https://www.reichelt.de/batterieclip-fuer-9-volt-block-vertikal-clip-9v-p6665.html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)
- [30x Duo-LEDs 0,19€/Stk.](https://www.reichelt.de/led-5-mm-bedrahtet-3-pin-rot-gruen-100-mcd-30--evl-339-1sursygw-p231037.html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)
- [4x Taster 0,31€/Stk.](https://www.conrad.de/de/p/omron-b3f-1020-drucktaster-24-v-dc-0-05-a-tastend-1-st-bag-2591184.html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)
- [Schiebeschalter 1,29€/Stk.](https://www.conrad.de/de/p/tru-components-1386942-css-1201-schiebeschalter-50-v-dc-0-3-a-1-x-aus-ein-1-st-1570488.html)
- [Spannungsregler 0,50€/Stk.](https://www.conrad.de/de/p/stmicroelectronics-l7805acv-spannungsregler-linear-to-220ab-positiv-fest-1-5-a-1184958.html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)
- [Keramikkondensator 330nF 0,14€/Stk.](https://www.conrad.de/de/p/tancap-ct4-0805y334m500a1t-keramik-kondensator-tht-330-nf-50-v-20-b-x-h-4-2-mm-x-25-mm-1-st-1578738.html)
- [Keramikkondensator 100nF 0,09€/Stk.](https://www.conrad.de/de/p/tru-components-tc-k100nf5-keramik-kondensator-tht-100-nf-50-v-20-1-st-1589524.html)

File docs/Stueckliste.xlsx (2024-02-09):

Stückliste
Bauteil | Menge | Bezeichnung
PCB (Vier-Gewinnt) | 1 | Vier_Gewinnt V2.1
ESP32 | 1 | U2
9V Batterie | 1
10 kΩ Widerstände | 4 | R1, R2, R3, R4
Buchsenleiste (15 Pin) | 2
Batterieclip | 1 | U3
Duo-LED | 30 | P1 - P30
Taster | 4 | S1, S2, S3, S4
Schiebeschalter (angewinkelt) | 1 | S0
Spannungsregler (L7805ACV) | 1 | U1
Keramikkondensator (330 nF) | 1 | C1
Keramikkondensator (100 nF) | 1 | C2

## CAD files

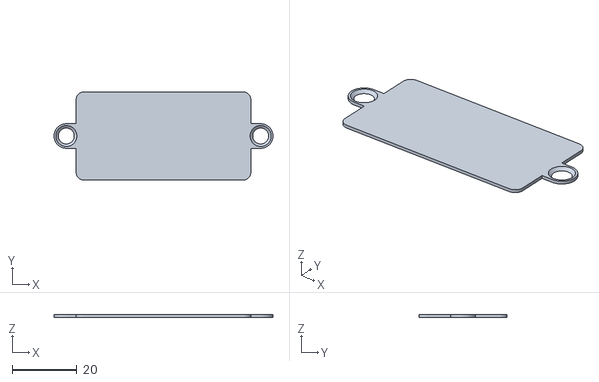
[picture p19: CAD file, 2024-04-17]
3D_Print/AW1082-02-73-50-002_Batterie_Abdeckung.stl
67.6 x 27.2 x 0.8

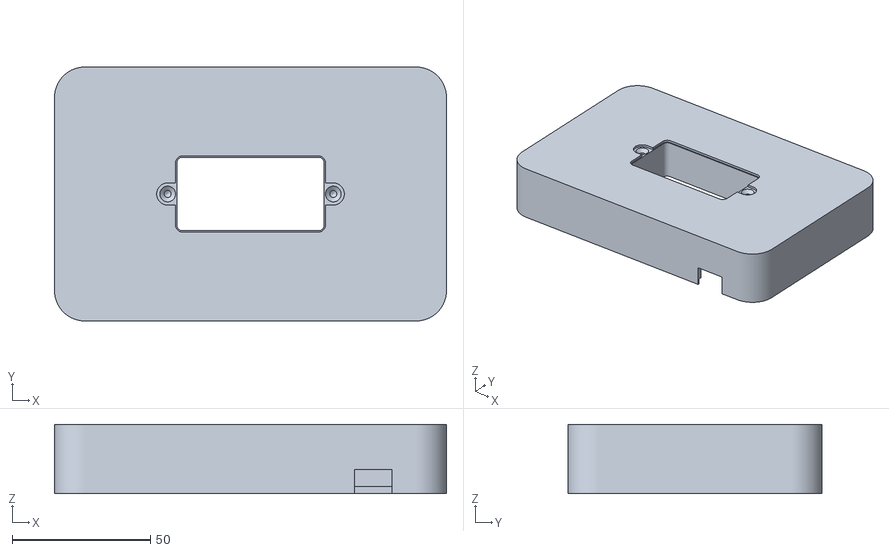
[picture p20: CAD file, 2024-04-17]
3D_Print/AW1082-02-73-50-001_Gehäuse.stl
142.0 x 92.0 x 25.0

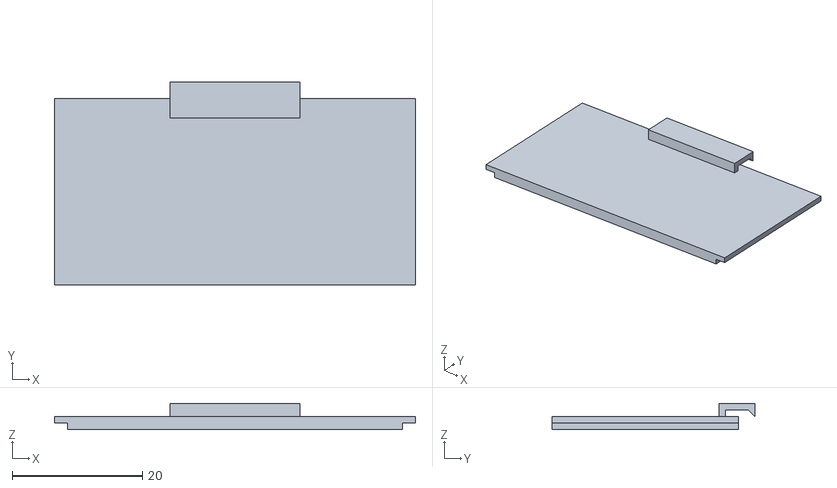
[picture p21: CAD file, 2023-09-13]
3D_Print/Deckel_4-Gewinnt.stl
55.4 x 31.1 x 4.00

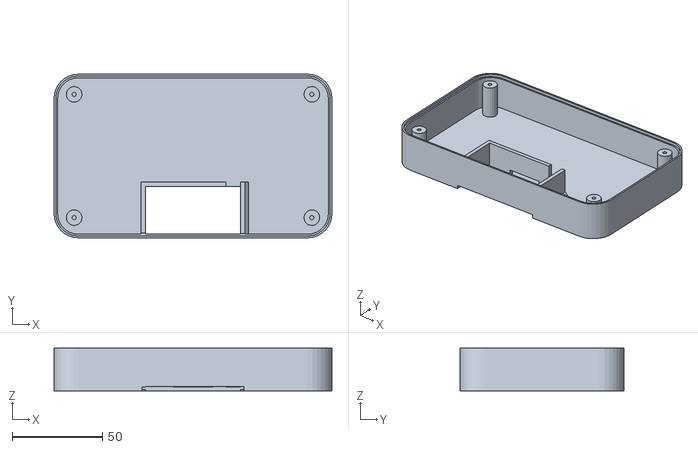
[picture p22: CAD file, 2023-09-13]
3D_Print/Gehäuse_4-Gewinnt.stl
154.4 x 90.9 x 23.7

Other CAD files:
3D_Print/AW1082-02-73-50-001_Gehäuse.prt
3D_Print/AW1082-02-73-50-002_Batterie_Abdeckung.prt
3D_Print/Gehäuse_4-Gewinnt.prt

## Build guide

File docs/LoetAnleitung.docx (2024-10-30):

# Lötanleitung

# Stückliste

Bauteil | Menge | Bezeichnung
PCB (Vier-Gewinnt) | 1 | Vier_Gewinnt V2.1
ESP32 | 1 | U2
9V Batterie | 1
10 kΩ Widerstände | 4 | R1, R2, R3, R4
Buchsenleiste (15 Pin) | 2
Batterieclip | 1 | U3
Duo-LED | 30 | P1 - P30
Taster | 4 | S1, S2, S3, S4
Schiebeschalter (angewinkelt) | 1 | S0
Spannungsregler (L7805ACV) | 1 | U1
Keramikkondensator (330 nF) | 1 | C1
Keramikkondensator (100 nF) | 1 | C2

# Hinweis vorab

Beim Löten ist es zu empfehlen, wenn Sie mit den flachsten Komponenten starten und sich zu den immer höheren Komponenten heranarbeiten. Die Bauteile werden immer auf die Seite gesetzt, auf der auch die Bauteilgrundfläche zu erkennen ist.

# Erster Lötdurchgang

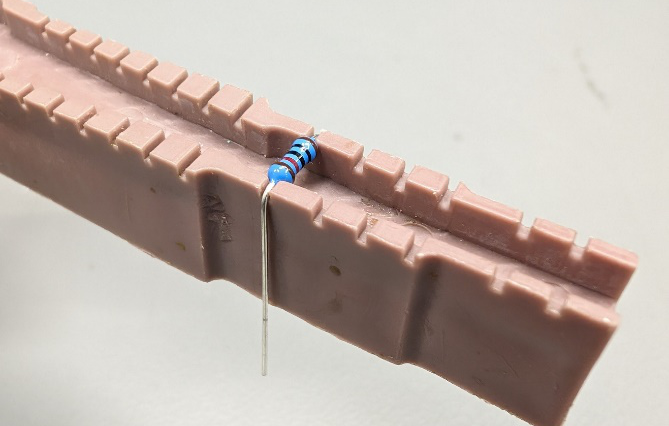
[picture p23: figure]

Im ersten Lötdurchgang werden die Widerstände und Taster angelötet. Dabei sollte man zuerst die Beine der Widerstände zurechtbiegen. Hierfür kann eine Biegelehre/ Biegeschablone verwendet werden, um die Widerstände einheitlich und passend für die Löcher zu biegen (siehe Bild). Die Widerstände gehören an die Lötstellen, die mit R1-R4 beschriftet sind.

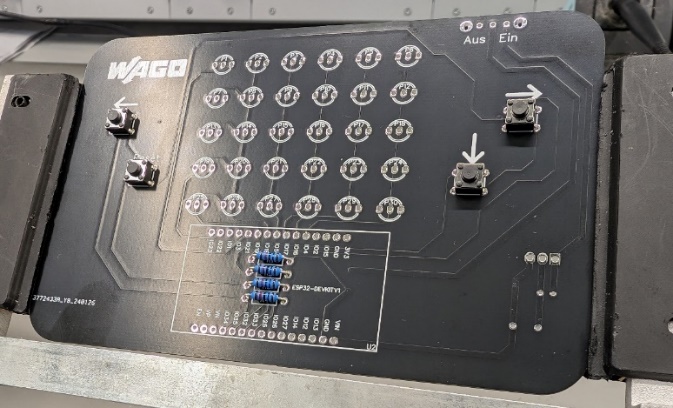
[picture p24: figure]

Zusammen mit den Widerständen kann man die Taster löten. Bei den Tastern gilt es auf die richtige Ausrichtung zu achten. Die Taster sollten horizontal zur Platine angebracht werden. In anderer Ausrichtung passen die Taster nicht in die Lötstellen. Die Lötstellen sind mit S1-S4 beschriftet. Beim Einführen in die Lötstellen sollten die Taster von allein halten und einfach festgelötet werden können.

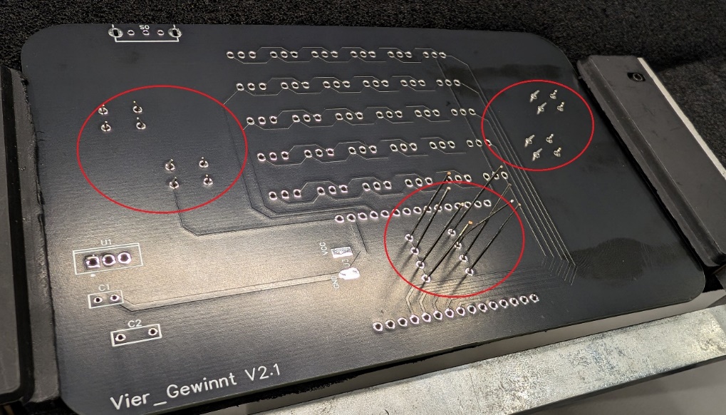
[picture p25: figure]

# Zweiter Lötdurchgang

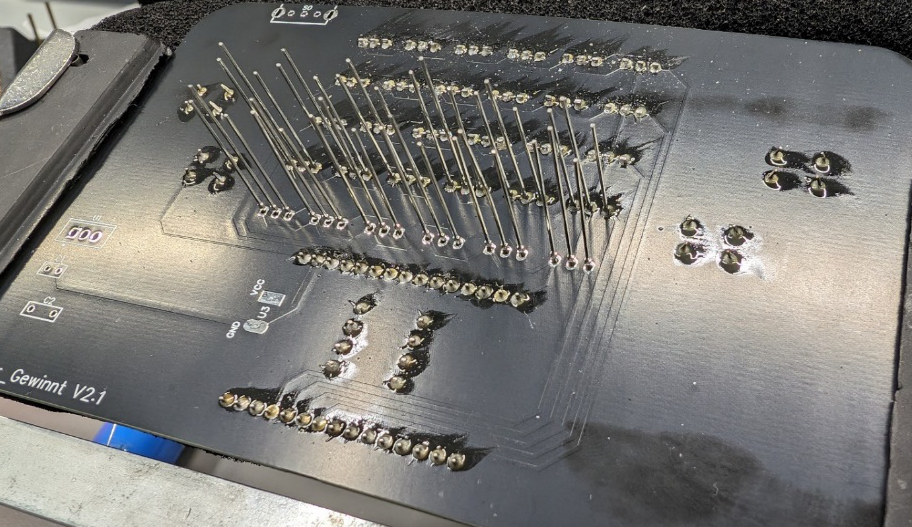
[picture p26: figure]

Im nächsten Lötdurchgang werden die Duo-LEDs (P1-P30) festgelötet. Dies ist einer der schwersten Teile am Löten. Dabei sollte wieder auf die Polung der LEDs geachtet werden. Um das gewünschte Ergebnis zu erzielen, muss man darauf achten, dass die abgeflachte Seite der LEDs nach rechts zeigt, wenn man auf die Seite mit den Markierungen für die LEDs schaut. Die abgeflachte Seite findet man am leichtesten, wenn man von oben auf die LEDs schaut. Diese Seite ist ebenfalls die Seite mit dem dickeren und längeren Bein. Wenn dies nicht berücksichtigt wird, dann leuchten die LEDs nicht in der gewünschten Farbe. Nachdem alle LEDs richtig ausgerichtet in der Platine Stecken kann man eine Schaumstoffmatte als Halterung verwenden und gemeinsam einspannen. So fallen die LEDs nicht wieder raus, wenn man die Platine umdreht zum Löten. Beim Löten sollte man sich am besten von Reihe zu Reihe durcharbeiten. So beginnt man beispielsweise in der oberen Reihe und lötet diese. Im Anschluss knipst man die Beinchen dieser Reihe ab, damit man besser an die Reihe darunter gelangt. Nun setzt man dieses Vorgehen für alle Reihen fort.

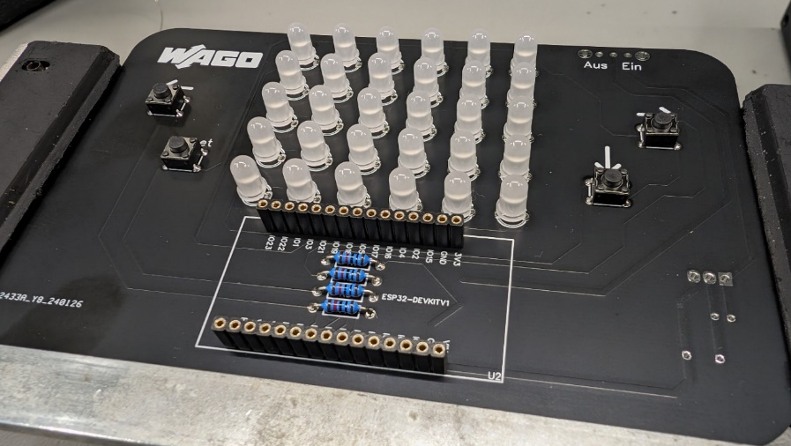
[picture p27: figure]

Neben den LEDs kann man nun auch die Buchsenleisten festlöten. Dabei sucht man eine Reihe mit passender Länge oder man knipst sich eine Reihe in passende Länge. Diese steckt man ebenfalls in die Platine und befestigt sie mit der Schaumstoffmatte. Allerdings sollte berücksichtigt werden, dass die Buchsenleisten gerade auf der Platine sitzen, denn am Ende müssen dort die Beine des ESP32 rein. Wenn die Buchsenleisten schief sitzen, dann passt der ESP32 nicht mehr in sie hinein.
Nachdem diese Schritte abgeschlossen sind, ist die Vorderseite der Platine fertig und wir können uns mit der Rückseite beschäftigen.

# Rückseite verlöten

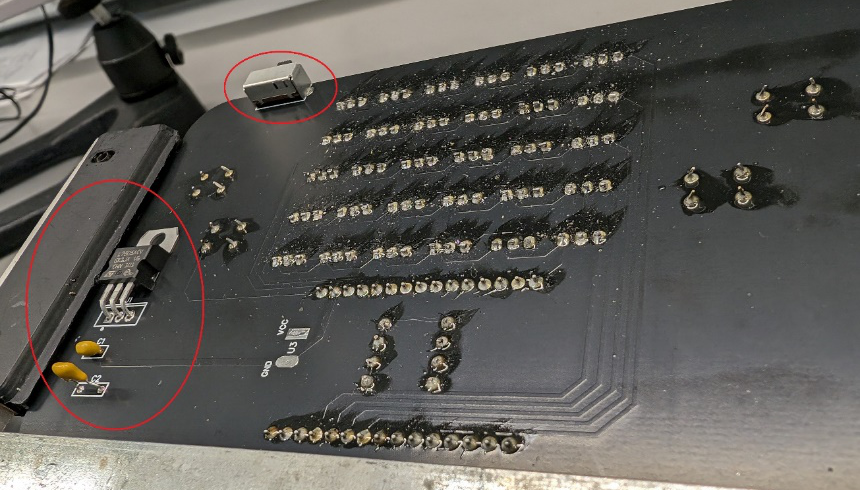
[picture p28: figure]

Auf der Rückseite wird zum einen die Spannungsversorgung festgelötet. Die besteht aus zwei Keramikkondensatoren (C1 und C2) und einem Spannungsregler (U1). Außerdem wird der Schiebeschalter (S0) zum Ein- und Ausschalten angebracht. Bei den Keramikkondensatoren sollte man darauf achten, dass sie keine Polung haben. Dies erkennt man daran, dass die Beinchen gleich lang sind. Außerdem sind die Kondensatoren beschriftet. Wenn man ganz genau hinschaut, erkennt man auf dem Kondensator C1 die Kennung 334 und auf dem Kondensator C2 die Kennung 104. Die Kennungen sollten beachtet werden und nicht der Abstand der Beinchen. Dieser kann unter Umständen variieren. Des Weiteren sollte man die Kondensatoren möglichst tief in die Platine stecken. Beim Spannungsregler muss wieder auf die Ausrichtung geachtet werden. Es gibt verschiedene Erkennungsmerkmale. Zum einen befindet sich auf der Platine ein kleiner Punkt. Dieser Punkt markiert den Anschlusspin ‚1‘. Welchem Beinchen des Spannungswandlers dies entspricht, kann im Datenblatt nachgeschaut werden. Alternativ erkennt man ein schmales Rechteck auf der Platine, welches die Seite des Spannungswandlers mit der dünnen metallischen Scheibe kennzeichnet. Um den Spannungswandler besser mit der Schaumstoffmatte befestigen zu können, kann man ihn vor dem Anlöten umklappen. Der Schiebeschalter sollte mit dem Schalthebel nach außen zeigen.

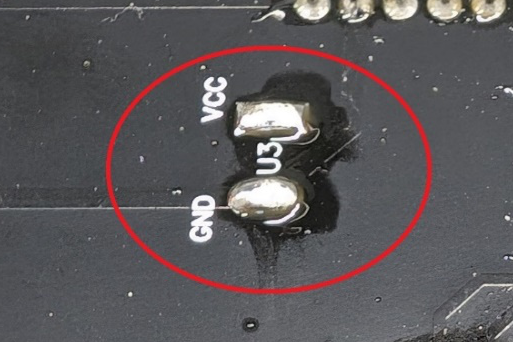
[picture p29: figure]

Zum Schluss fehlt nur noch der Batterieclip für die 9V Batterie. Da für den Batterieclip nur Lötflächen und keine Löcher vorgesehen sind ist hier das Vorgehen etwas anders als bei den anderen Lötstellen. Deshalb sollte man die Lötflächen ohne den Batterieclip mit Lötzinn benetzen. Danach kann man das Lötzinn erneut erhitzen und somit verflüssigen. So kann man die Kupferenden des Batterieclips in das Lötzinn schieben. Hierbei muss selbstverständlich auf die Polung geachtet werden. Schwarze Kabel stehen für Ground (Abkürzung GND) und das rote Kabel steht für VCC.

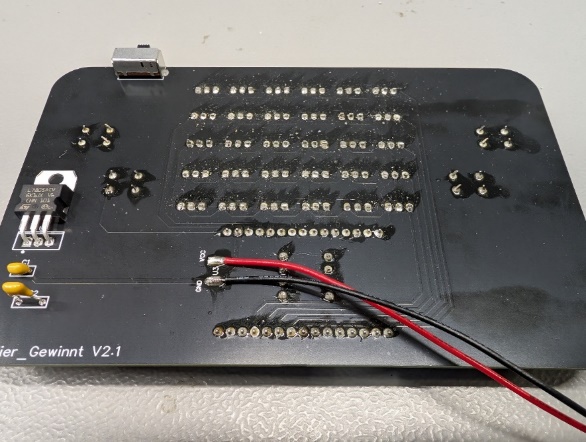
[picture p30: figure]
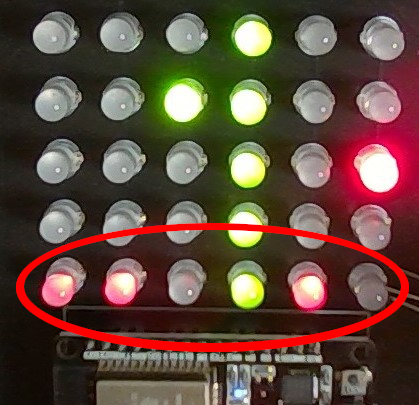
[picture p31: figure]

# Häufige Fehler

LED-Reihe leuchtet dauerhaft

Falls eine Reihe von LEDs dauerhaft schwach leuchtet, sind die Kontakte einer der LEDs kurzgeschlossen. Die betroffene LED, typischerweise die LED, die in der Reihe überhaupt nicht leuchtet, sollte entlötet werden, um den Abstand der LED zu der Platine und somit den Kontaktflächen zu vergrößern.

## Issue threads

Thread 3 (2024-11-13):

Ergänzung von Aufgaben mit Duo-LEDs in den Einstiegsaufgaben

LKrumme2, 2024-11-13:
Bei Bedarf können die Einstiegsaufgaben mit Duo-LEDs ergänzt werden.

Original Issue von Andreas Epp am 15. September 2023

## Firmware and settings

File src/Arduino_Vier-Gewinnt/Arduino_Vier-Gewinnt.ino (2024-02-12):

#include <Arduino.h>
#include "Color.h"
#include "LEDMatrix.h"
#include "miniMax.h"


// Pin-Definitionen für die LEDs und Tasten
#define line1red 21
#define line2red 15  
#define line3red 2   
#define line4red 22
#define line5red 23

#define line1green 25
#define line2green 26
#define line3green 27
#define line4green 14
#define line5green 12

#define ground1 19
#define ground2 18
#define ground3 5
#define ground4 17
#define ground5 16
#define ground6 4

#define buttonL 34
#define buttonR 33
#define buttonRst 35
#define buttonD 32

// Konstanten für die LED-Matrix
const byte nColumns = 6;
const byte nRows = 5;

// Variablen für den Spielstatus
Color startColor = Color::RED;
int currentColumn = 0;
byte lastButton = 0;
Color currentColor = startColor;
byte countPlays = 0;
byte currentMenuNumber = 1;
bool multiplayer = LOW;
bool player1 = HIGH;
bool menu = HIGH;
bool won = LOW;
ulong lastTime;

// Array für die Pin-Belegung der LED-Matrix
byte LEDMatrixPins[nColumns * 3] = {ground1, ground2, ground3, ground4, ground5, ground6,
                                    line1red, line2red, line3red, line4red, line5red, 0,
                                    line1green, line2green, line3green, line4green, line5green, 0};

// Objekt der LED Matrix
LEDMatrix lm(LEDMatrixPins, nColumns, nRows);

// Objekt des MiniMax Algorithmus
miniMax minMax;

// Task für die Verlagerung auf einen zweiten Prozessor Kern
TaskHandle_t Task1;

// Methode zum updaten der Anzeige
void updateLEDMatrix(void * parameteter);

// Methode zum Auslesen und Verarbeiten der Tastereingaben 
void readButtons(bool);

// Methode zum Auslesen und Verarbeiten der Tastereingaben im Menu
void readButtons();

// Methode zum Zurücksetzen des Spiels
void reset();

// Methode zum Setzen eines Steins durch die AI
void AImove();

// Berechnet einen Zug mit dem Minimax und setzt diesen
bool miniMaxMove();

// Methode zum berechnen eines zufälligen Zuges
void randomMove();

// Methode zum Berechnen eines Zuges durch Beachtung von Regeln
bool rulebasedMove();

// Platziert einen Stein und wechselt den Spieler
void placeStone(byte column);

void setup() {
    // Konfiguration der Pins
    pinMode(ground1, OUTPUT);
    pinMode(ground2, OUTPUT);
    pinMode(ground3, OUTPUT);
    pinMode(ground4, OUTPUT);
    pinMode(ground5, OUTPUT);
    pinMode(ground6, OUTPUT);

    pinMode(line1red, OUTPUT);
    pinMode(line2red, OUTPUT);
    pinMode(line3red, OUTPUT);
    pinMode(line4red, OUTPUT);
    pinMode(line5red, OUTPUT);

    pinMode(line1green, OUTPUT);
    pinMode(line2green, OUTPUT);
    pinMode(line3green, OUTPUT);
    pinMode(line4green, OUTPUT);
    pinMode(line5green, OUTPUT);

    pinMode(buttonL, INPUT);
    pinMode(buttonR, INPUT);
    pinMode(buttonD, INPUT);
    pinMode(buttonRst, INPUT);

    // Erstellen der Task
    xTaskCreatePinnedToCore(
        updateLEDMatrix,    // Methode die verlagert wird
        "Task1",            // Name der Task
        1000,               // Speicher größe
        NULL,
        1,                  // Priorität
        &Task1,             // Task
        0                   // Prozessor Kern
    );

    // Serielle Kommunikation starten
    Serial.begin(9600);
}

// Regelt die Spiellogik
void loop() {
    if(menu){
        won = lm.update(menu);  
        lm.printNumber(currentMenuNumber);  // Bildet den aktuellen Spielmodus ab
        readButtons();
    }
    else{
        if(multiplayer){
            won = lm.update(menu);
            readButtons(won);
        }
        else{
            
            won = lm.update(menu);
            if(!player1 && !won){
                AImove();
            }

            if(player1 || won){
                // Tasten auslesen und Spielstatus aktualisieren
                readButtons(won);
            }
        }
    }
    delay(1);
}

// Methode zum updaten der Anzeige
void updateLEDMatrix(void * parameter){
    (void)parameter;
    for(;;){
        if(!lm.isDraw()){
            lm.setLEDs();
        }
        delay(1);
    }
}

// Methode zum Auslesen und Verarbeiten der Tastereingaben 
void readButtons(bool won) {
    if(digitalRead(buttonRst)){
        if(lastButton == buttonRst && millis() - lastTime >= 1000){
            reset();
        } else if(lastButton != buttonRst){
            lastButton = buttonRst;
            lastTime = millis();
        }
    } else if(!won && currentColumn != -1){
        int pos = currentColumn;
        if(digitalRead(buttonD)){
            if(lastButton != buttonD){
                lastButton = buttonD;
                placeStone(currentColumn);
                return;
            }
        } else if (digitalRead(buttonL)){
            if(lastButton != buttonL){
                lastButton = buttonL;
                pos = lm.findPossibleDestination(currentColumn-1, -1);
            }
        } else if (digitalRead(buttonR)){
            if(lastButton != buttonR){
                lastButton = buttonR;
                pos = lm.findPossibleDestination(currentColumn+1, 1);
            }
        } else{
            lastButton = 0;
        }
        if (pos >= 0) {
            // 
            lm.setLightValue(pos, currentColumn, (Color)((int)(currentColor)+2));
            currentColumn = pos;
        }
    } else{
        lastButton = 0;
    }
}

// Methode zum Auslesen und Verarbeiten der Tastereingaben im Menu
void readButtons(){
    // Tastenabfrage und Aktionen je nach gedrückter Taste
    if (digitalRead(buttonL)) {
        currentMenuNumber = 1;
        multiplayer = false;
    } else if (digitalRead(buttonR)) {
        currentMenuNumber = 2;
        multiplayer = true;
    } else if (digitalRead(buttonD)) {
        menu = false;
        lm.reset(currentColumn);
        player1 = HIGH;
        currentColor = startColor;
        currentColumn = 0;
        countPlays = 0;
    } 
}

// Methode zum Zurücksetzen des Spiels
void reset() {
    // Spiel zurücksetzen
    lm.reset(currentColumn);
    player1 = HIGH;
    currentColor = startColor;
    currentColumn = 0;
    menu = HIGH;
    countPlays = 0;
    lastTime = 0;
    lastButton = 0;
}

// Methode zum Setzen eines Steins durch die AI
void AImove(){
    // if(miniMaxMove()){
    //     Serial.println("MiniMax");
    //     return;
    // }
    if(rulebasedMove()){
        Serial.println("RuleBased");
        return;
    }
    randomMove();
    Serial.println("RandomMove");
}

// Platziert einen Stein und wechselt den Spieler
void placeStone(byte column){
    lm.setLightValue(column, currentColumn, currentColor);
    player1 = !player1;
    if (player1) {
        currentColor = startColor;
    } else {
        currentColor = Color::GREEN;
    }
    currentColumn = lm.findPossibleDestination(0, 1);
    countPlays++;
}

// Methode zum Berechnen eines Zuges durch Beachtung von Regeln
bool rulebasedMove(){
    // Gibt die besten Reihen von rot und grün
    std::vector<std::vector<std::pair<int, int>>> bestPaths = lm.getBestPath();
    for (byte i = 0; i < bestPaths.size(); i++){
        std::vector<std::pair<int, int>> bestPath = bestPaths.at(i);
        if(bestPath.size() >= 2){ // Ist es mindestens eine 2er Reihe?
            if(bestPath[1].first < bestPath[2].first){ 
                if(bestPath[1].second > bestPath[2].second){ // Die Reihe liegt in einer Diagonalen nach oben
                    if(bestPath[1].first > 0 && bestPath[1].second < nRows-1){ // Kontermöglichkeit links von der Reihe
                        std::pair<int, int> pos = lm.findPossibleDestination(bestPath[1].first-1);
                        if(pos.first == bestPath[1].first-1 && pos.second == bestPath[1].second+1){
                            placeStone(pos.first);
                            return true;
                        }
                    }
                    if(bestPath[1].first < nColumns-1 && bestPath[1].second > 0){ // Kontermöglichkeit rechts von der Reihe
                        std::pair<int, int> pos = lm.findPossibleDestination(bestPath[bestPath.size()-1].first+1);
                        if(pos.first == bestPath[bestPath.size()-1].first+1 && pos.second == bestPath[bestPath.size()-1].second-1){
                            placeStone(pos.first);
                            return true;
                        }
                    }
                }
                else if(bestPath[1].second < bestPath[2].second){ // Die Reihe liegt in einer Diagonalen nach unten
                    if(bestPath[1].first > 0 && bestPath[1].second > 0){ // Kontermöglichkeit links von der Reihe
                        std::pair<int, int> pos = lm.findPossibleDestination(bestPath[1].first-1);
                        if(pos.first == bestPath[1].first-1 && pos.second == bestPath[1].second-1){
                            placeStone(pos.first);
                            return true;
                        }
                    }
                    if(bestPath[1].first < nColumns-1 && bestPath[1].second < nRows-1){ // Kontermöglichkeit rechts von der Reihe
                        std::pair<int, int> pos = lm.findPossibleDestination(bestPath[bestPath.size()-1].first+1);
                        if(pos.first == bestPath[bestPath.size()-1].first+1 && pos.second == bestPath[bestPath.size()-1].second+1){
                            placeStone(pos.first);
                            return true;
                        }
                    }
                }
                else{ // Die Reihe liegt in einer Zeile
                    if(bestPath[1].first > 0){
                        std::pair<int, int> pos = lm.findPossibleDestination(bestPath[1].first-1);
                        if(pos.second == bestPath[1].second){ // Kontermöglichkeit links von der Reihe
                            placeStone(pos.first);
                            return true;
                        }
                    }
                    if(bestPath[1].first < nColumns-1){
                        std::pair<int, int> pos = lm.findPossibleDestination(bestPath[bestPath.size()-1].first+1);
                        if(pos.second == bestPath[1].second){ // Kontermöglichkeit rechts von der Reihe
                            placeStone(pos.first);
                            return true;
                        }
                    }
                }
            }
            else{ // Die Reihe liegt in einer Spalte
                std::pair<int, int> pos = lm.findPossibleDestination(bestPath[1].first);
                if(pos.first != -1 && pos.second == bestPath[1].second-1){
                    placeStone(pos.first);
                    return true;
                }
            }
        }
    }
    return false; // Es wurde kein Zug gefunden
}

// Methode zum berechnen eines zufälligen Zuges
void randomMove(){
    std::vector<byte> columns = lm.findPossibleColumns(currentColumn);
    byte length = columns.size();
    if(length >= 1){
        srand(millis());
        int rdm = rand() % length;

        std::pair<int, int> pos = lm.findPossibleDestination(columns.at(rdm));
        if(pos.first >= 0){
            placeStone(pos.first);
        }
    }
}

// Berechnet einen Zug mit dem Minimax und setzt diesen
// bool miniMaxMove(){
//     ulong time = millis();
//     byte startDepth = 4;
//     byte startRowToLose = 3;
//     byte standardRowToLose = 4;
//     byte depth = 6;
//     byte toDeepToCalculate = 6;
//     int nothingFound = -1;

//     if(countPlays >= 6){        //Ab 6 Spielzüge soll der Minimax bis eine Spieltiefe von 6 berechnen
//         if(countPlays >= 20){   //Ab 20 Spielzüge soll der Minimax das ganze Spiel vorberechnen
//             depth = 30 - countPlays;
//         }
//         std::pair<int, int> bestPlay = minMax.run(lm.LEDvalues, depth, standardRowToLose);
//         Serial.println("Best move");
//         Serial.print(bestPlay.first);
//         Serial.println(" ");
//         Serial.println(bestPlay.second);
//         if(bestPlay.first >= nothingFound && bestPlay.first != toDeepToCalculate){
//             placeStone(bestPlay.second);
//             float u = (millis()-time) / 1000;
//             Serial.print("Die Berechnung dauerte: ");
//             Serial.print(u);
//             Serial.println(" Sekunden");
//             return true;
//         }
//         else
//         {
//             float u = (millis()-time) / 1000;
//             Serial.print("Die Berechnung dauerte: ");
//             Serial.print(u);
//             Serial.println(" Sekunden");
//             return false;
//         }
//     }
//     else
//     {
//         std::pair<int, int> bestPlay = minMax.run(lm.LEDvalues, startDepth, startRowToLose);
//         Serial.println("Best move");
//         Serial.print(bestPlay.first);
//         Serial.println(" ");
//         Serial.println(bestPlay.second);
//         if(bestPlay.first >= -1 && bestPlay.first != toDeepToCalculate){
//             placeStone(bestPlay.second);
//             float u = (millis()-time) / 1000;
//             Serial.print("Die Berechnung dauerte: ");
//             Serial.print(u);
//             Serial.println(" Sekunden");
//             return true;
//         }
//         else
//         {            
//             float u = (millis()-time) / 1000;
//             Serial.print("Die Berechnung dauerte: ");
//             Serial.print(u);
//             Serial.println(" Sekunden");
//             return false;
//         }
//     }
//     float u = (millis()-time) / 1000;
//     Serial.print("Die Berechnung dauerte: ");
//     Serial.print(u);
//     Serial.println(" Sekunden");
//     return false; // Es wurde kein Zug gefunden
// }

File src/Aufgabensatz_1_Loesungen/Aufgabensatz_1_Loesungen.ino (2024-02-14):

// Lösung zu den Aufgaben für das 4-Gewinnt Spiel

// Pins definieren
// Aufgabe 2
// #define LED 23

// Aufgabe 3
// #define Masse 22

// Aufgabe 4
// #define LED1 13
// #define LED2 22
// #define Masse1 12
// #define Masse2 23

void setup() {
  // Aufgabe 2
  // pinMode(LED, OUTPUT);
  
  // Aufgabe 3
  // pinMode(Masse, OUTPUT);

  // pinMode(LED1, OUTPUT);
  // pinMode(LED2, OUTPUT);
  // pinMode(Masse1, OUTPUT);
  // pinMode(Masse2, OUTPUT);

}

void loop() {
  // Aufgabe 2
  // digitalWrite(LED, HIGH);
  // delay(2000);
  // digitalWrite(LED, LOW);
  // delay(2000);

  // Aufgabe 3
  // digitalWrite(LED, HIGH);
  // digitalWrite(Masse, LOW);
  // delay(2000);
  // digitalWrite(Masse, HIGH);
  // delay(2000);

  // Aufgabe 4
  // 4.1
  // y Koordinate
  // digitalWrite(LED1, HIGH);
  // x Koordinate
  // digitalWrite(Masse1, LOW);
  // digitalWrite(LED2, LOW);
  // digitalWrite(Masse2, HIGH);
  
  // 4.2
  // Erste LED einschalten 
  // digitalWrite(LED1, HIGH);
  // digitalWrite(Masse1, LOW);
  // digitalWrite(LED2, LOW);
  // digitalWrite(Masse2, HIGH);
  // Verzögerung
  // delay(1);
  // Erste LED ausschalten
  // digitalWrite(LED1, LOW);
  // digitalWrite(Masse1, HIGH);
  //Zweite LED einschalten 
  // digitalWrite(LED2, HIGH);
  // digitalWrite(Masse2, LOW);
  // Verzögerung
  // delay(1);
  // zweite LED ausschalten
  // digitalWrite(LED2, LOW);
  // digitalWrite(Masse2, HIGH);
}

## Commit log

2023-08-23 Prototyp 3 Animation und Aufbau
2023-08-29 Add slide switch
2023-08-30 Update und Korrektur
2023-08-30 kleine Änderungen an der Struktur
2023-08-30 kleine Änderungen an der Struktur 2
2023-08-30 Add PCB-Layout
2023-08-30 Add PCB Layout and rename circuit file
2023-08-31 Wechsel der Pinbelegung
2023-08-31 Buttons versuch 1
2023-08-31 Buttons L und R funktionieren
2023-08-31 Add Round Corner and switch 2 Outputs
2023-08-31 Methoden possibleDestination und findPossibleDestination hinzugefügt Alle Button funktionieren
2023-08-31 Add hole for screws
2023-09-04 Formatierung und Kommentare für Methoden
2023-09-04 Update layout and circuit
2023-09-05 Erweiterung der findPossibleDestination Methode, um eine weitere Funktiond drawControl Methode eingefügt
2023-09-06 Hinzufügen der Bauteilliste
2023-09-07 drawControl Methode fertig und findPossibleDestination Methode verändert
2023-09-07 Menu zum wechseln des Spielmodus
2023-09-08 Code Aufgeräumt (Serial.print entfernt)
2023-09-08 Veränderung des Rückgabetyps der run Methode
2023-09-08 Einbindung des MiniMax
2023-09-11 Suchtiefen des Minimax getestet
2023-09-11 Fertige Einbindung der AI + Verlagerung auf 2 Kerne
2023-09-11 Hinzufügen der Löt-Anleitung
2023-09-12 Hinzufügen der Anleitungen und Beschreibungen
2023-09-12 Reset Button veränder
2023-09-12 Optimierung der Ai
2023-09-14 PCB fertig, Stückliste angepasst
2023-09-14 Hinzufügen eines Arduino-Projekts und ergänzen der ReadMe.md
2023-09-15 Aufgaben ergänzt und Lösungen hinzugefügt
2023-10-27 Wago Logo im PCB verändert und Löcher entfernt
2023-11-17 Schaltplan und PCB verändert. Veränderungen: Spannungsversorgung und Anordnung
2023-11-17 Gerber-Dateien hinzugefügt
2023-11-17 Veränderung der Gerber-Dateien
2024-01-15 Update Stückliste.md
    Ergänzung des Links von dem Spannungsregler
2024-01-15 Hinzufügen der Buchsenleisten
2024-01-15 Kleine Anpassungen
    [Stueckliste.xlsx]
2024-01-18 Fertigstellung der zu druckenden Platine V2.1 und hinzufügen der Arbeitsplatzaustattung für das Löten
    [Stueckliste.xlsx]
2024-02-02 Einbau von einem Enum für die Farbe der LED + MinMax Aufruf entfernt, dadurch ist der einzelspielermodus nur noch Regelbasiert
2024-02-02 Die Reset Animation wurde verändert.
    [LEDMatrix.cpp, main.cpp]
2024-02-02 Anleitung angepasst und Fotos hinzugefügt
2024-02-09 Anleitung und Stücklisten angepasst
    [Stueckliste.xlsx]
2024-02-12 Übertragen des VSC-Codes in die Arduino IDE
2024-02-13 Umbenennen des doc-Ordners
    [Stueckliste.xlsx]
2024-02-13 Rename doc-Folder
    [Stueckliste.xlsx]
2024-02-13 löschen des redirects
2024-02-13 Hinzufügen der Programmieranleitung
2024-02-14 Ergänzen der index.md und weiterer Dokumentationen
2024-02-14 Verlinkung der Zip
2024-02-14 kleine Änderung der index.md
2024-02-14 Hinzufügen des Download-Attributs
2024-02-14 Lösungen für die Erweiterten Aufgaben
2024-02-14 Fertigstellen der index.md und ordnen der Programme
2024-02-14 Reset Animation bei Unentschieden geändert
    [LEDMatrix.cpp]
2024-02-14 Hinzufügen des QR-Codes und Anpassen des Download-Links der index.md
2024-02-15 Den Quellcode in den docs Ordner verschoben, da nur so die Praktikanten ohne einen Github Account darauf zugreifen können
2024-02-15 Index Datei für die Verschiebung des Quellcodes angepasst
2024-02-15 Kopieren der Zip in den src-Ordner
2024-02-15 kleine Korrektur des Links
2024-02-15 Verschieben der config.yml und bereitstellen der Zip
2024-03-27 Hinzufügen eines Ortes für die Produktnummer
2024-10-30 Überarbeitung der Lötanleitung.
    Lötanleitung wurde Überarbeitet.
    Änderungen:
    - Bessere Verständlichkeit bei einigen Passagen.
    - Schiebeschalter S0 wurde der Anleitung hinzugefügt.
    - Häufige Fehler wurden hinzugefügt zur schnelleren Fehlersuche.
2024-10-30 Adresse von Bulde.7z geupdated
    Bundle.7z wurde in den docs Ordner verschoben. Die Adresse wurde aktualisiert, damit die Datei wieder erreichbar ist.
2024-10-30 Bauteilliste zum Einkleben erstellt
    Bauteilliste zum Einkleben in die Kästen erstellt.
2024-11-06 Arbeitsplatzausstattung aktualisiert
    Papier und Glasreiniger wieder zur Tabelle hinzugefügt.
2024-11-13 Änderung des remote_theme
